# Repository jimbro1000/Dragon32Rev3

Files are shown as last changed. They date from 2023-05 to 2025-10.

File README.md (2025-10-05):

# DRAGON 32 RECREATION Rev 3 #

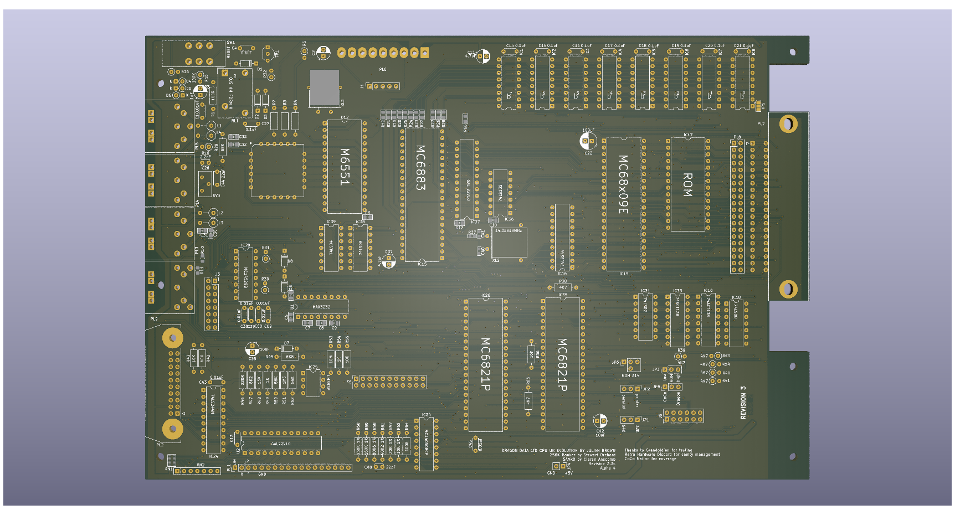
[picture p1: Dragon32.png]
Dragon 32 revision 3 render


This project started as a recreation of the SA2120 CPU Mainboard
for the 1982 Dragon Data **Dragon 32**

Everything (excluding modifications) is taken from the SA2120
schematics. Where this version changes is that the options to
use banks of 16K DRAM is gone, you must use 64K DRAMs, with it
goes all the extra circuitry for configuring the memory for
different types of chip.

The ROM is now a single 27C256 eprom with an option to switch
between two images using JP6 or to allow the rom to be
automatically selected from the PIA.

A second ROM selection jumper is available at JP3 to be used
when a 27C512 is fitted. This swaps the value to A15 between
high and low. When a 27C256 is fitted this must be set low.

Hidden on the back of the board is a solder pad jumper (JP7) that
also needs setting to handle a 27C256 or 27C512. Bridging pad
1 sets pin 22 of the rom to ground, using pad 3 sets the
pin to use the ROM select signal shared with pin 20. When a
27C512 is fitted this must be set to pad 1.

The video circuits have been isolated from the rest of the
board to improve output quality.

A second (internal) cartridge port has been added, by way of
a 2x20 header, along with an additional +5V/Gnd pickup point
for further internal expansion.

An optional 256K banking solution is incorporated using the
design for Stewart Orchard's upgrade board and GAL design.
<https://gitlab.com/sorchard001/dragon-256k-banker-board>

## Progress ##

In the current state (3.3) most of the board is tested except
for the additional audio capabilities, SAMx8 compatibility and
the logic controlled switching of keyboard configuration.

## Modifications ##

### Joysticks ###

The two joystick ports provide a second fire button capability
wired to consecutive keyboard rows, as per the Tandy CoCo.
Unless a two button joystick is used this make no difference to
the operation of the computer. It also requires the use of 6-pin
DIN sockets, these are pin compatible with the 5-pin originals
so a regular single button joystick can still be used.

The two extra buttons can also be disabled by omitting L3 and L4.

### Parallel Port ###

A jumper (JP2) has been introduced to bypass the logic inverter
on the STROBE line. When bypassed the parallel port should
operate as a communication port for DRIVEWIRE.

### Memory Addressing ###

The board is configurable between 32k and 64k ram addressing
using jumper JP1. In most scenarios there is no reason to
disable the 64k option.

The upgrade to 256K needs the 4164s swapping for 41256s. The
pre-bridged jumper at JP5 needs cutting. The SAM also needs 
to be replaced with a 74LS785. The optional components can 
then be fitted and should work without further alteration.

The required JED file for the GAL22V10 that drives the memory
banking is in the CPLD folder of the project.

The 256K upgrade can be replaced with a SAMx8 upgrade board.
This replaces the SAM chip and the tristate buffer that sits
between the RAM and the CPU, and also allows connection to
the second data path that goes to the VDG. With this in place
the DRAM (either 4164 or 41256) is redundant, as is the GAL 
that provides the 256K banker capability.

### Video Port ###

The board includes a third connector for the video mezzanine
card. This exposes the video board to the CPU side of the
data bus along with control signals that would permit 
programming of the video for additional features. With a 
stock 6847 that might be to include a programmable character
"rom" but I'm also working on a synthetic FPGA based replacement
for the 6847 that will allow much bigger changes such as 
swappable/programmable colour palettes.

### Audio ###

The board provides a position to mount a custom implementation
of the AY sound generator. This provides three channels of 
synthesised sound without using the CPU intensive system that
the Dragon comes with by default. The capabilities are the same
as those of the Spectrum 128 models. You can even mix the old
and new methods of sound generation to create more noise!

Theoretically other sound generators could be used but the AY
option provides a cheap, capable mechanism that follows a 
standard familiar to users of other computers from the era.

### Keyboard ###

The board places a GAL chip between the input register of
PIA 1 and the keyboard connector. The GAL could be ommitted
and jumpers used to hardwire the connections to either
Dragon or CoCo compatibility.

With a GAL in place the wiring is controlled by a jumper.

## Substitutions ##

Many of the original components are simply unobtainable or
just very hard (and expensive) to locate. The transistors
will need modern substitutes as the BC141, BC212 and 2N2369
are all obsolete but thankfully these are fairly run-of-the-mill
transistors and shouldn't cause any particular issues.

The CPU and PIAs are all fairly easy to obtain online
and possibly even new (MC6821s are still made and there
are lots of compatible alternatives). A and B rated components
should all be usable but make sure the processor is an "09e".
The Hitachi HD6309 is usable but may cause crashes in some
software due to lazy coding.

Ciaran Anscomb's samX4 can be used to replace the SAM
chip and can be configured to operate as a 74LS783 or a
74LS785 to suit.

### The Future ###

As these parts become harder to find it is inevitable that
replacements and redesigns will be needed. After much hard
work by the Dragon and CoCo community the *only* IC on the
required, that is not still made or in plentiful supply is
the MC6847 VDG (the LM1889 on the PAL board is also in
limited supply but there are ways around the issue).

The Hitachi HD6309 has been in production until recently due
to military supply contracts making it easily accessible and
at reasonable cost. Ultimately this will diminish but with
supplies still high it seems likely to be available for a long
time yet.

The MC6821 is available new but at eye watering prices as
it is only made in small batches. The WD65C21 is a direct
swap and in much higher supply making it generally cheaper
than remaining original NOS parts.

The LS and CD discrete logic chips are all generally easy
to obtain and all have more modern equivalents that can be
swapped in.

Some searching may be needed for the cartridge port connector.
A direct replacement part is listed in the EDAC catalogue but
is only made to demand which requires an order of some 200
units. Lower quality but compatible parts can be found online.

Ultimately all of the parts will become hard to obtain but
for the foreseeable future the board should remain viable.

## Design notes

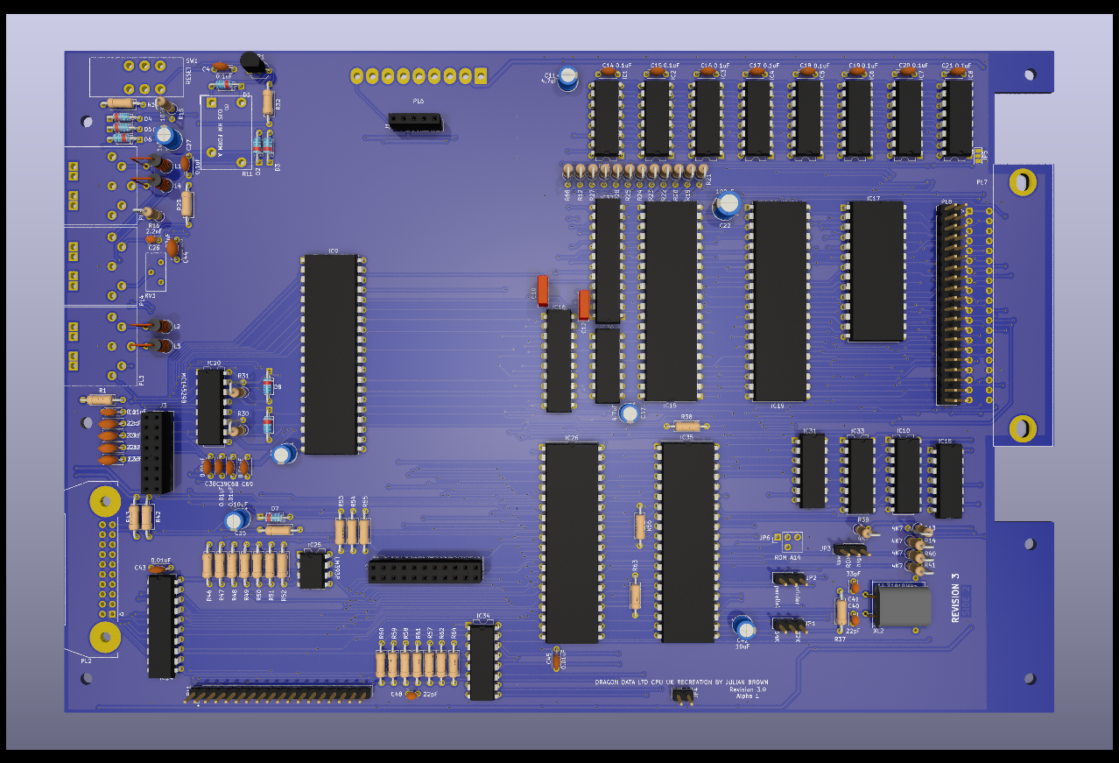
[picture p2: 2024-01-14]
Dragon32plusAlpha1.png

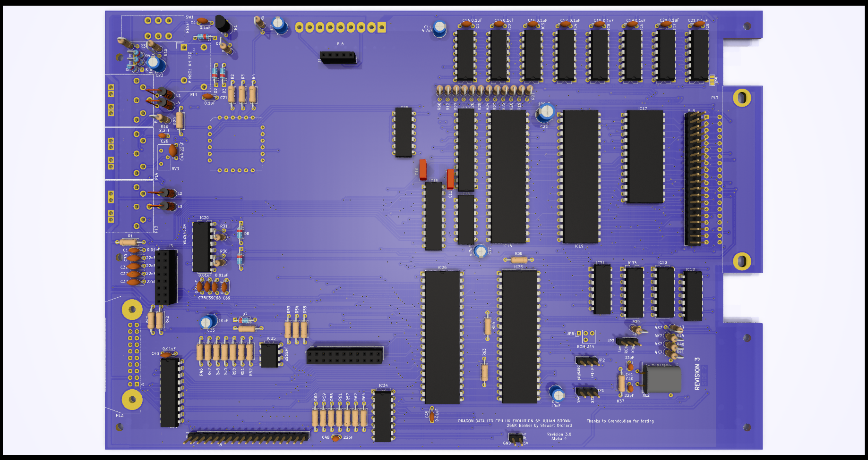
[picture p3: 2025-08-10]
Dragon32plus.png

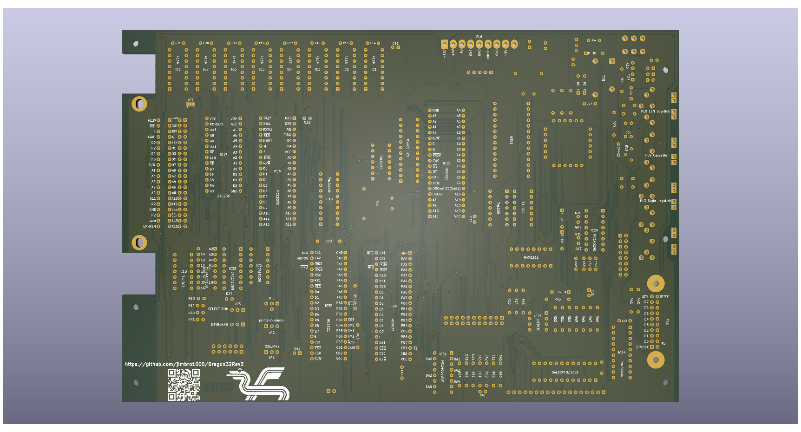
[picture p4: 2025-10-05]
Dragon32reverse.png

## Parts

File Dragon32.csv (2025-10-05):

Reference | Value | Datasheet | Footprint | Qty | DNP | DigiKey | LCSC
C1,C13,C38,C39,C43,C45,C68,C69 | 0.01uF | https://www.vishay.com/docs/45171/kseries.pdf | Capacitor_THT:C_Disc_D4.3mm_W1.9mm_P5.00mm | 8 |  | BC1101CT-ND,BC2662CT-ND
C2,C35,C42 | 10uF | https://www.we-online.com/katalog/datasheet/860010372001.pdf,~ | Capacitor_THT:CP_Radial_D5.0mm_P2.50mm | 3 |  | 732-8593-1-ND
C3,C5,C6,C7,C8,C9,C10,C12 | 100nF | ~ | PCM_Capacitor_SMD_AKL:C_0805_2012Metric_Pad1.18x1.45mm_HandSolder | 8 |  |  | C1711
C4,C14,C15,C16,C17,C18,C19,C20,C21,C27 | 0.1uF | https://www.vishay.com/docs/45171/kseries.pdf | Capacitor_THT:C_Disc_D4.3mm_W1.9mm_P5.00mm | 10 |  | BC1101CT-ND
C11,C37 | 4.7uF | https://datasheets.kyocera-avx.com/tap.pdf | Capacitor_THT:CP_Radial_D5.0mm_P2.50mm | 2 |  | 478-8984-1-ND
C22 | 100uF | https://www.we-online.com/katalog/datasheet/860010372006.pdf | Capacitor_THT:CP_Radial_D6.3mm_P2.50mm | 1 |  | 732-8598-1-ND
C23 | 1uF | https://www.we-online.com/katalog/datasheet/860020772005.pdf | Capacitor_THT:CP_Radial_D5.0mm_P2.50mm | 1 |  | 732-8966-1-ND
C26 | 2.2nF | https://www.vishay.com/docs/45171/kseries.pdf | Capacitor_THT:C_Disc_D3.0mm_W2.0mm_P2.50mm | 1 |  | BC1074CT-ND
C30,C31,C32,C33 | 22nF | https://www.vishay.com/docs/45171/kseries.pdf | PCM_Capacitor_SMD_AKL:C_0805_2012Metric_Pad1.18x1.45mm_HandSolder | 4 |  |  | C1729
C40 | 22pF | https://connect.kemet.com:7667/gateway/IntelliData-ComponentDocumentation/1.0/download/datasheet/C315C220K2G5TA7301 | PCM_Capacitor_SMD_AKL:C_0603_1608Metric_Pad1.08x0.95mm_HandSolder | 1 |  |  | C1653
C41 | 33pF | https://www.vishay.com/docs/45171/kseries.pdf | PCM_Capacitor_SMD_AKL:C_0603_1608Metric_Pad1.08x0.95mm_HandSolder | 1 |  |  | C1663
C44 | 22nF | https://www.vishay.com/docs/45171/kseries.pdf | Capacitor_THT:C_Disc_D5.0mm_W2.5mm_P5.00mm | 1 |  | BC2677CT-ND
C48 | 22pF | https://connect.kemet.com:7667/gateway/IntelliData-ComponentDocumentation/1.0/download/datasheet/C315C220K2G5TA7301 | Capacitor_THT:C_Disc_D3.0mm_W2.0mm_P2.50mm | 1 |  | 399-13930-1-ND
D1,D2,D3,D7,D8,D9 | 1N914 | http://www.vishay.com/docs/85622/1n914.pdf | Diode_THT:D_DO-35_SOD27_P7.62mm_Horizontal | 6 |  | 1N914FS-ND
D4,D5,D6 | 1N914 | http://www.vishay.com/docs/85622/1n914.pdf | Diode_THT:D_DO-35_SOD27_P2.54mm_Vertical_KathodeUp | 3 |  | 1N914FS-ND
IC1,IC2,IC3,IC4,IC5,IC6,IC7,IC8 | 4164 | https://4donline.ihs.com/images/VipMasterIC/IC/INFN/INFNS18263/INFNS18263-1.pdf | Package_DIP:DIP-16_W7.62mm | 8
IC10 | 74ACT138 | http://www.ti.com/lit/gpn/sn74LS138 | Package_DIP:DIP-16_W7.62mm | 1 |  |  | C1547282
IC15 | MC6883 | http://www.colorcomputerarchive.com/coco/Documents/Datasheets/MC6883 Synchronous Address Multiplexer (Motorola).pdf | Package_DIP:DIP-40_W15.24mm | 1
IC16,IC24 | 74LS244N | http://www.ti.com/lit/ds/symlink/sn74ls244.pdf | Package_DIP:DIP-20_W7.62mm | 2 |  | 296-1653-5-ND | C22374098
IC17 | 27C256 | http://ww1.microchip.com/downloads/en/DeviceDoc/doc0014.pdf | Package_DIP:DIP-28_W15.24mm | 1
IC18,IC38 | 74LS08 | http://www.ti.com/lit/gpn/sn74LS08 | Package_DIP:DIP-14_W7.62mm | 2 |  |  | C22394768
IC19 | MC6809E | http://pdf.datasheetcatalog.com/datasheet/motorola/MC68B09S.pdf | Package_DIP:DIP-40_W15.24mm | 1
IC20 | MC14529B |  | Package_DIP:DIP-16_W7.62mm | 1 |  | CD4529BCN-ND
IC25 | LM393P | http://www.ti.com/lit/ds/symlink/lm393.pdf | Package_DIP:DIP-8_W7.62mm | 1 |  | 296-1398-5-ND | C5209
IC26,IC35 | MC6821 |  | Package_DIP:DIP-40_W15.24mm | 2 |  | 2156-MC6821CS-2156-ND
IC31 | 74LS02N | http://www.ti.com/lit/gpn/sn74ls02 | Package_DIP:DIP-14_W7.62mm | 1 |  | 296-1627-5-ND | C22374091
IC33 | 74ACT138N | http://www.ti.com/lit/gpn/sn74LS138 | Package_DIP:DIP-16_W7.62mm | 1 |  | 296-1639-5-ND
IC34 | MC14050BCP | https://media.digikey.com/pdf/Data%20Sheets/ON%20Semiconductor%20PDFs/MC14049B,50B_Rev7.pdf | Package_DIP:DIP-16_W7.62mm | 1 |  | 296-2056-ND
IC36 | 74LS132 | http://www.ti.com/lit/gpn/sn74LS132 | Package_DIP:DIP-14_W7.62mm | 1
IC37 | GAL |  | Package_DIP:DIP-24_W7.62mm | 1
IC39 | 74LS04 | http://www.ti.com/lit/gpn/sn74LS04 | Package_DIP:DIP-14_W7.62mm | 1 |  |  | C22374093
J1 | Video Output Female | ~ | Connector_PinSocket_2.54mm:PinSocket_1x05_P2.54mm_Vertical | 1
J2 | Board Interconnect Female | ~ | Connector_PinSocket_2.54mm:PinSocket_2x11_P2.54mm_Vertical | 1
J3 | Conn_02x08_Odd_Even | ~ | Connector_PinSocket_2.54mm:PinSocket_2x08_P2.54mm_Vertical | 1
J4 | PSG Audio | ~ | Dragon:AY-QTHT | 1
J5 | Config | ~ | Connector_PinHeader_2.54mm:PinHeader_2x06_P2.54mm_Vertical | 1
JP1 | 32k/64k | ~ | Connector_PinHeader_2.54mm:PinHeader_1x03_P2.54mm_Vertical | 1
JP2 | printer/comms | ~ | Connector_PinHeader_2.54mm:PinHeader_1x03_P2.54mm_Vertical | 1
JP3 | SELECT ROM | ~ | Connector_PinHeader_2.54mm:PinHeader_1x03_P2.54mm_Vertical | 1
JP4 | 5vPower | ~ | Connector_PinHeader_2.54mm:PinHeader_1x02_P2.54mm_Vertical | 1
JP5 | Z8hi/low | ~ | Jumper:SolderJumper-3_P1.3mm_Open_Pad1.0x1.5mm | 1
JP6 | ROM A14 |  | Dragon:Jumper_4 | 1
JP7 | 27C512 | ~ | Jumper:SolderJumper-3_P1.3mm_Open_Pad1.0x1.5mm | 1
JP8 | KBD_Config | ~ | Connector_PinHeader_2.54mm:PinHeader_1x03_P2.54mm_Vertical | 1
L1,L2,L3,L4 | 3.3uH | ~ | Inductor_THT:L_Axial_L7.0mm_D3.3mm_P5.08mm_Vertical_Fastron_MICC | 4 |  | 495-5561-1-ND
PL1 | Conn_01x18_Pin | ~ | Connector_PinHeader_2.54mm:PinHeader_1x18_P2.54mm_Vertical | 1
PL2 | Printer | https://media.digikey.com/pdf/Data%20Sheets/CW%20Industries%20PDFs/CWN-300%20Ordering.pdf | Connector_IDC:IDC-Header_2x10-1MP_P2.54mm_Latch_Horizontal | 1 |  | CHR20G-ND
PL3 | DIN-6 J/S R | https://www.dem-uk.com/deltron-components/Data/Product_Downloads/deltron-671-0501-5-way-din-socket-data.pdf | Dragon:DIN-6_DELTRON_671-0601_Horizontal | 1
PL4 | DIN-5 (180) Cassette | https://www.dem-uk.com/deltron-components/Data/Product_Downloads/deltron-671-0501-5-way-din-socket-data.pdf | Dragon:DIN-5_DELTRON_671-0501_45deg_Horizontal | 1
PL5 | DIN-6 J/S L | https://www.dem-uk.com/deltron-components/Data/Product_Downloads/deltron-671-0501-5-way-din-socket-data.pdf | Dragon:DIN-6_DELTRON_671-0601_Horizontal | 1
PL6 | Conn_01x09_Male | https://app.adam-tech.com/products/download/data_sheet/241222/lhd-xx-ts-data-sheet.pdf | Connector_Molex:Molex_KK-396_A-41791-0009_1x09_P3.96mm_Vertical | 1 |  | 2057-LHD-09-TS-ND
PL7 | EDAC 392-040-558-201 | https://files.edac.net/edac/content/342/342-040-558-212%20-%20EDAC%20Card%20Edge%20Connector.PDF | Dragon:Edge_2x20_P2.54mm_OvalMP | 1 |  | 151-395-040-558-201-ND
PL8 | EDAC 392-040-558-201 |  | Connector_PinHeader_2.54mm:PinHeader_2x20_P2.54mm_Vertical | 1 |  | 151-395-040-558-201-ND
PL9 | Serial | http://www.mouser.com/ds/2/18/40_c091_abd_e-75918.pdf | Dragon:DIN-7_DELTRON_671-0701_Horizontal | 1
R1 | 100R | ~ | Resistor_THT:R_Axial_DIN0207_L6.3mm_D2.5mm_P10.16mm_Horizontal | 1 |  | CF14JT100RCT-ND
R2,R3,R4,R49,R54 | 1K | ~ | Resistor_THT:R_Axial_DIN0207_L6.3mm_D2.5mm_P10.16mm_Horizontal | 5 |  | CF14JT1K00CT-ND
R5 | 1K | ~ | Resistor_THT:R_Axial_DIN0207_L6.3mm_D2.5mm_P2.54mm_Vertical | 1
R10,R11 | 4K7 | ~ | Resistor_SMD:R_0805_2012Metric_Pad1.20x1.40mm_HandSolder | 2 |  | CF14JT4K70CT-ND | C17673
R12,R19,R20,R21,R22,R23,R24,R25,R26,R27,R28,R66 | 22R | ~ | PCM_Resistor_SMD_AKL:R_0805_2012Metric_Pad1.20x1.40mm_HandSolder | 12 |  |  | C17561
R13,R14,R30,R31,R32,R39,R40,R41 | 4K7 | ~ | Resistor_THT:R_Axial_DIN0207_L6.3mm_D2.5mm_P2.54mm_Vertical | 8 |  | CF14JT4K70CT-ND
R15,R36 | 100K | ~ | Resistor_THT:R_Axial_DIN0207_L6.3mm_D2.5mm_P2.54mm_Vertical | 2 |  | CF14JT100KCT-ND
R16 | 33K | ~ | Resistor_THT:R_Axial_DIN0207_L6.3mm_D2.5mm_P2.54mm_Vertical | 1 |  | CF14JT33K0CT-ND
R29 | 68K | ~ | Resistor_THT:R_Axial_DIN0207_L6.3mm_D2.5mm_P10.16mm_Horizontal | 1 |  | CF14JT68K0CT-ND
R37 | 1K5 | ~ | PCM_Resistor_SMD_AKL:R_0603_1608Metric_Pad1.05x0.95mm_HandSolder | 1 |  |  | C22843
R38,R63 | 4K7 | ~ | Resistor_THT:R_Axial_DIN0207_L6.3mm_D2.5mm_P10.16mm_Horizontal | 2 |  | CF14JT4K70CT-ND
R42,R43,R55,R56 | 10K | ~ | Resistor_THT:R_Axial_DIN0207_L6.3mm_D2.5mm_P10.16mm_Horizontal | 4 |  | CF14JT10K0CT-ND
R45 | 6K8 | ~ | Resistor_THT:R_Axial_DIN0207_L6.3mm_D2.5mm_P10.16mm_Horizontal | 1 |  | CF14JT6K80CT-ND
R46 | 220R | ~ | Resistor_THT:R_Axial_DIN0207_L6.3mm_D2.5mm_P10.16mm_Horizontal | 1 |  | CF14JT220RCT-ND
R47 | 8K2 | ~ | Resistor_THT:R_Axial_DIN0207_L6.3mm_D2.5mm_P10.16mm_Horizontal | 1 |  | CF14JT8K20CT-ND
R48 | 15K | ~ | Resistor_THT:R_Axial_DIN0207_L6.3mm_D2.5mm_P10.16mm_Horizontal | 1 |  | CF14JT15K0CT-ND
R50,R52 | 56K | ~ | Resistor_THT:R_Axial_DIN0207_L6.3mm_D2.5mm_P10.16mm_Horizontal | 2 |  | CF14JT56K0CT-ND
R51 | 1M5 | ~ | Resistor_THT:R_Axial_DIN0207_L6.3mm_D2.5mm_P10.16mm_Horizontal | 1 |  | CF14JT1M50CT-ND
R53 | 10M | ~ | Resistor_THT:R_Axial_DIN0207_L6.3mm_D2.5mm_P10.16mm_Horizontal | 1 |  | CF14JT10M0CT-ND
R57 | 20K 1% | ~ | Resistor_THT:R_Axial_DIN0207_L6.3mm_D2.5mm_P10.16mm_Horizontal | 1 |  | RNF14FTD20K0CT-ND
R58 | 80K6 1% | ~ | Resistor_THT:R_Axial_DIN0207_L6.3mm_D2.5mm_P10.16mm_Horizontal | 1 |  | RNF14FTD80K6CT-ND
R59 | 160K 1% | ~ | Resistor_THT:R_Axial_DIN0207_L6.3mm_D2.5mm_P10.16mm_Horizontal | 1 |  | S160CACT-ND
R60 | 330K 1% | ~ | Resistor_THT:R_Axial_DIN0207_L6.3mm_D2.5mm_P10.16mm_Horizontal | 1 |  | S330KCACT-ND
R61 | 40K2 1% | ~ | Resistor_THT:R_Axial_DIN0207_L6.3mm_D2.5mm_P10.16mm_Horizontal | 1 |  | RNF14FTD41K2CT-ND
R62 | 10K 1% | ~ | Resistor_THT:R_Axial_DIN0207_L6.3mm_D2.5mm_P10.16mm_Horizontal | 1 |  | RNF14FTD10K0CT-ND
R64 | 100K | ~ | Resistor_THT:R_Axial_DIN0207_L6.3mm_D2.5mm_P10.16mm_Horizontal | 1 |  | CF14JT100KCT-ND
RL1 | OJS HM FORM A | https://www.te.com/commerce/DocumentDelivery/DDEController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 | Dragon:OJS HM 10A Relay | 1 |  | 41-OJS-SH-105HMF,00000-ND
RN1 | 4k7 | ~ | PCM_Resistor_SMD_AKL:R_Array_Convex_8x0602 | 1 | DNP | Y1472CT-ND | C713463
RN2 | 4K7x6 | http://www.vishay.com/docs/31509/csc.pdf | Resistor_THT:R_Array_SIP7 | 1 |  |  | C39096
RV3 | 470R | ~ | Potentiometer_THT:Potentiometer_Bourns_3386X_Horizontal | 1 |  | 3386H-103LF-ND
SW1 | RESET | https://www.ckswitches.com/media/1402/fpush.pdf | Dragon:Button_AlpsAlpine_SPUN190900 | 1 |  | 401-1225-ND
TR1 | PN2222 | http://www.farnell.com/datasheets/296634.pdf | Package_TO_SOT_THT:TO-92_Inline_Wide | 1 |  | KSD1616AYTACT-ND | C896866
U1 | MAX3232 | https://datasheets.maximintegrated.com/en/ds/MAX3222-MAX3241.pdf | Package_DIP:DIP-16_W7.62mm | 1
U2 | GAL22V10 |  | Package_DIP:DIP-24_W7.62mm | 1
U12 | M6551 |  | Package_DIP:DIP-28_W15.24mm | 1
XL2 | 14.31818MHz | https://www.ctscorp.com/wp-content/uploads/MP.pdf | Crystal:Crystal_HC49-U_Horizontal | 1 |  | CTX088-ND
XL3 | 1.8432MHz | ~ | Crystal:Crystal_HC18-U_Horizontal_1EP_style2 | 1

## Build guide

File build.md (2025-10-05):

# Dragon Rev 3 Build Instructions #

## Introduction ##

This is a rough guide on how to assemble the 
Dragon Rev 3 board. It assumes you have 
collected together all the parts you will need 
using the bill of materials in the project 
repository.

## Preparation ##

Any big PCB build requires planning and 
preparation to make things go smoothly. The 
Dragon Rev 3 needs a significant number of 
components, some of them can be hard to obtain.

The choice of video and SAM components make a
substantial difference to how the board is built
and it is worth starting here and working back
from these choices.

Clean the mainboard to remove contaminants, soapy
water first, dry and then a wipe down with 
isopropyl alcohol.

Make sure you have a good supply of solder, a
temperature controlled soldering iron. If you
are using lead based solder set the temperature
to between 320C and 370C - this depends on the 
exact solder composition and the iron being used. 
The board can tolerate higher for lead-free solder.

A ready supply of solder flux can be really
helpful if you find yourself having to remove a
component from the board.

You will need short tipped, angled wire cutters
for trimming the component leads after soldering.
Don't cut the leads right down to the board or deep
into the solder.

It is also a good idea to have a multimeter on hand
to check component values and test for any shorts
after soldering.

The project repository on GitHub includes an
interactive Bill Of Materials that allows you to
cross-reference components against position on
the board (and mark off all the parts that you've
fitted). To use this download the ibom.html file
to your computer and open it from the local file
system (this should open up a web browser).

If you can't or don't want to use the iBOM it is
a good idea to print off the Dragon Assembly 
PDF on to large form paper and mark the positions 
off from there as they are fitted to help avoid
getting lost.

## Build Order ##

It is advised to work with the lowest profile
components first - resistors, then diodes, then 
capacitors, transistors, etc.

Leaving the chip sockets until last helps as they 
tend to get in the way when fitting other items.

### Build Options ###

The board can be built to three different 
configurations:

    1. 64K with standard SAM
    2. 256K with updated 74LS785 SAM
    3. 512K with SAMx8

### SMD Parts ###

Build option 1 and 2 require that the surface
mount resistors North of the SAM position must
be fitted.

For option 2 the capacitors at C12 and C10 are
required.

RN1 is not required if RN2 is fitted (and
vice-versa).

The remaining SMD parts are required for all
three build options.

### Through Hole Resistors ###

Fit resistors first making sure the solder is
forming on both sides of the board, not just
the bottom.

Regardless of board configuration all of the
resistors should be fitted.

Save the two potentiometer resistors RV1 and RV2
for later.

### Diodes ###

Fit all 9 diodes in much the same way as the
resistors but making sure the polarity marking
matches the board. D4, D5 and D6 all require
the cathode to face up. The cathode should be
connected to the pad labelled K

### Inductors ###

If you want to have the option of two button
joysticks (non-standard but used in some
CoCo games) then you'll need to fit all 4
inductors (L1-L4).

If you only want single button joysticks you
only need to fit L1 and L2.

Soldering is the same as for resistors.

### Through Hole Capacitors ###

If you are building option 1 or 2, C14
to C21 must be fitted.

Other than this fit all capacitors making 
sure that the tantalum and electrolytic
capacitors are fitted the right way around.

Tantalum capacitors have a + symbol next to
the positive side. Electrolytic capacitors
have an arrow pointing to the negative side.

The board is marked to show a + next to the
positive side and a filled semicircle on the
negative side.

It is worth saving two of the long legs
after trimming the legs back. You can use
these for securing the crystals.

Save the trim pot capacitor C7 for later.

### Transistors ###

TR1 is an NPN transistor driving the coil of
the cassette remote relay. It uses a wide
TO-92 footprint.

Make sure the transistor is fitted the
right way around according to the outline
printed on the board.

### Jumper Posts ###

The board has 5 sets of jumpers that
need to be fitted with clips.

JP1 sets the RAM size if the board is
to be used as a Dragon 32.

JP2 controls whether the printer strobe
signal is inverted or not. For regular
printer use the "printer" option must
be used. If the strobe is to be used as
a bit-bang serial port (for drivewire
or CoCo compatibility), the "parallel"
option must be used.

JP3 allows you to control pin A15 of the
ROM. This is only relevant if the ROM
is a 27C512.

JP6 controls pin A14 of the ROM. There are
3 options, high, low or PIA controlled.
The PIA controlled setting is used by the
Dragon 64. This is only of use for a
27C256 or 27C512 rom.

JP8 configures the keyboard matrix
connections to switch between Dragon
and CoCo standards (using a Dragon
keyboard).

### Solder Jumpers ###

JP5 is used to fix the signal to Z8.
This is useful if 64k chips are used or
256k chips need to be used without a
74LS785 SAM.

### Connectors ###

The keyboard connector can be vertical or
a horizontal as desired. Original boards
used a vertical orientation but later boards
and the D64 moved to horizontal to avoid 
clashing with the keyboard itself. I
recommend using the horizontal option as
it leaves more space for connectors.

The joystick, serial and cassette port 
connectors have an overlapping design, if 
you want to get them nicely lined up start 
with the 5-pin cassette socket and tack it 
in place on a single pin.

You can then do the same with the two
joystick ports (6-pin or 270deg 5-pin)
and align them to the edge of the board.
This can be a tricky task so don't rush
it.

The power board connector needs to be 
fitted with the vertical guide towards
the bottom of the board (assuming you
don't have a plain pin header).

The cartridge port connector can be very
entertaining to fit. The pins like to
bend in transit so you'll likely find
yours do not line up on the first attempt.
It is very easy to bend the pins on the
cheaper connectors resulting in the pin
not fitting properly. Double check that
all pins have fitted through the mounting
holes on the board before soldering.

### Variable Components ###

RV3 needs to be fitted at an angle if
it is adjusted from the side.

### Crystals ###

Assuming you have the larger housed
crystals you will need to bend the legs
so the crystal lies flush with the board.
This is not essential but it is 
recommended. Two additional solder points
are provided for each crystal to allow a
wire to be formed over the body and 
prevent the crystal being moved. A
convenient source for the wire to do this
is the long legged capacitors you 
hopefully saved earlier.

### Sockets ###

When fitting the sockets make sure the
orientation is correct and the notch of
the socket matches the outline on the
board.

Most of the chips are aligned with the 
notch to the top of the board but RAM, ROM
and SAM chips have the notch towards
the bottom of the board.

As with the header pins it can be a 
little tricky to get the sockets to fit
flush and aligned. Tacking one pin at 
each end of the socket to hold it in
place and then heating one pin while
adjusting the position gives a good
result.

Be very careful to avoid bridging the
pins on the socket while soldering.
It is worth checking with a multimeter
to double check as the pins can 
bridge on the top of the board, hidden
underneath the socket.

### Before Fitting Chips ###

As a precaution, before fitting the
chips to the board it is worth making
sure none of the voltage pins of the
power board connector are shorted to
ground (that would be bad).

### Fitting Chips ###

Make sure you have a grounding strap on your
wrist (or ankle) and it is actually connected
to a proven ground point (radiators are a 
good source). The LM1889 and DRAM chips are
very susceptible to static discharge! Leave
these until last.

Fit all your chips paying very careful attention
to orientation, notches must match with the
board. Fitting chips the wrong way round will 
likely destroy them when the power is switched
on.

### Keyboard Connection ###

The keyboard must be fitted to the right of
the arrow on PL1. The two pins to the left
are used for providing power to the keyboard.

### First Power Up ###

When powering on for the first time always be
prepared to turn the power off in a hurry. 

If anything smokes or looks to be getting hot, turn
the power off immediately. You most likely have a 
short (you did check for shorts?) or a polarised
capacitor in backwards.

### Troubleshooting ###

If the relay doesn't click on powering up (assuming
you fitted one) and there is no picture at all, the
chances are the CPU is not cycling. Either it hasn't
come out of reset or is being locked up by another
line.

A bad PIA can cause the CPU to run very, very slowly
by generating interrupt requests at high frequency.
Try removing the PIAs and try running without them.

Check the reset line is going high (about 5V) and the
same again for halt, mrdy, extal, xtal, bs and ba pins.
If any of these are low it can stop the CPU operating.

Check the Q and E pins are oscillating at (about) 
0.9MHz, no clock means no CPU. You can also check
the SAM is receiving the full 14MHz clock from the
crystal.

If all is well with those pins, test the address and
data lines with an oscilloscope or logic probe. You
should see activity with the lines moving from high
to low.

If the CPU is doing nothing it may be faulty, either
test the CPU in a known good machine or try a different
CPU.

If the CPU is proven good you can turn your attention
to the SAM, this governs the CPU activity and memory
addressing. I've yet to see one fail but if it does
you have no hope of getting the computer to work until
it is replaced. More likely the SAM is not getting 
the input signals it needs to operate.

Check the clock input and the Q/E output of the SAM.
If the clock is present and correct, check the SAM 
is generating RAM addressing signals on the Z lines 
and RAS/CAS lines.

The SAM also decides what device is being addressed
it does this though a multiplexer at IC33. Check the
operation of this chip carefully. 

## Options ##

### Keyboard ###

If there is no need to support a CoCo keyboard setup
the GAL at U2 can be omitted. Instead just connect
the pins across the chip. Don't connect the top pair
as these are power and ground. RN1/2 can also be
omitted.

If it is required the GAL can be a 16V8 or 22V10, in
both cases the chip must be fitted to the left end
of the socket. RN1 or RN2 must be fitted if a GAL is
used.

### Serial Port ###

The RS232 setup can be omitted if the board is to
be used as a Dragon 32 or CoCo. In this scenario
U1, U12, IC38, IC39, XL3 and PL9 can all be omitted from
the build.

### Video ###

The board is designed to work with separate plug-in
video boards. At the simplest end these are either
NTSC or PAL composite output. More complex solutions
can be switched between formats, include the lower-case
extension or extended video options.

The video board is *not* part of this design and needs
to be obtained separately.

### SAM ###

The original SN74LS783 / MC6883 SAM chip limits the 
board to using 4164 64kb x 1 DRAM chips with 128 
row refresh (256 row refresh will not work).

A later, optional, version of the SAM chip is
available. Still with the Motorola MC6883 code but
with the logic identifier SN74LS785. These extend
the compatibility options to use 256 row refresh
DRAM chips. This version of the SAM chip is needed
for the 256kb x 1 DRAM chips. Obtaining this version
of the SAM can be tricky, if you plan to build the
256k version of the board please make sure you have
the chip first to avoid disappointment.

It is possible to use a modern replacement for the
SAM courtesy of Ciaran Anscomb. The preferred 
option is the SAMx8 plugin board that replaces the
SAM chip completely (and RAM).

See https://www.6809.org.uk/dragon/samx8/ for more
details.

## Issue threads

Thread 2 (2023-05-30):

DSD signal is not wired on phase 2

jimbro1000, 2023-05-30:
The DSD safety feature is missing in the phase 2 design and needs adding in

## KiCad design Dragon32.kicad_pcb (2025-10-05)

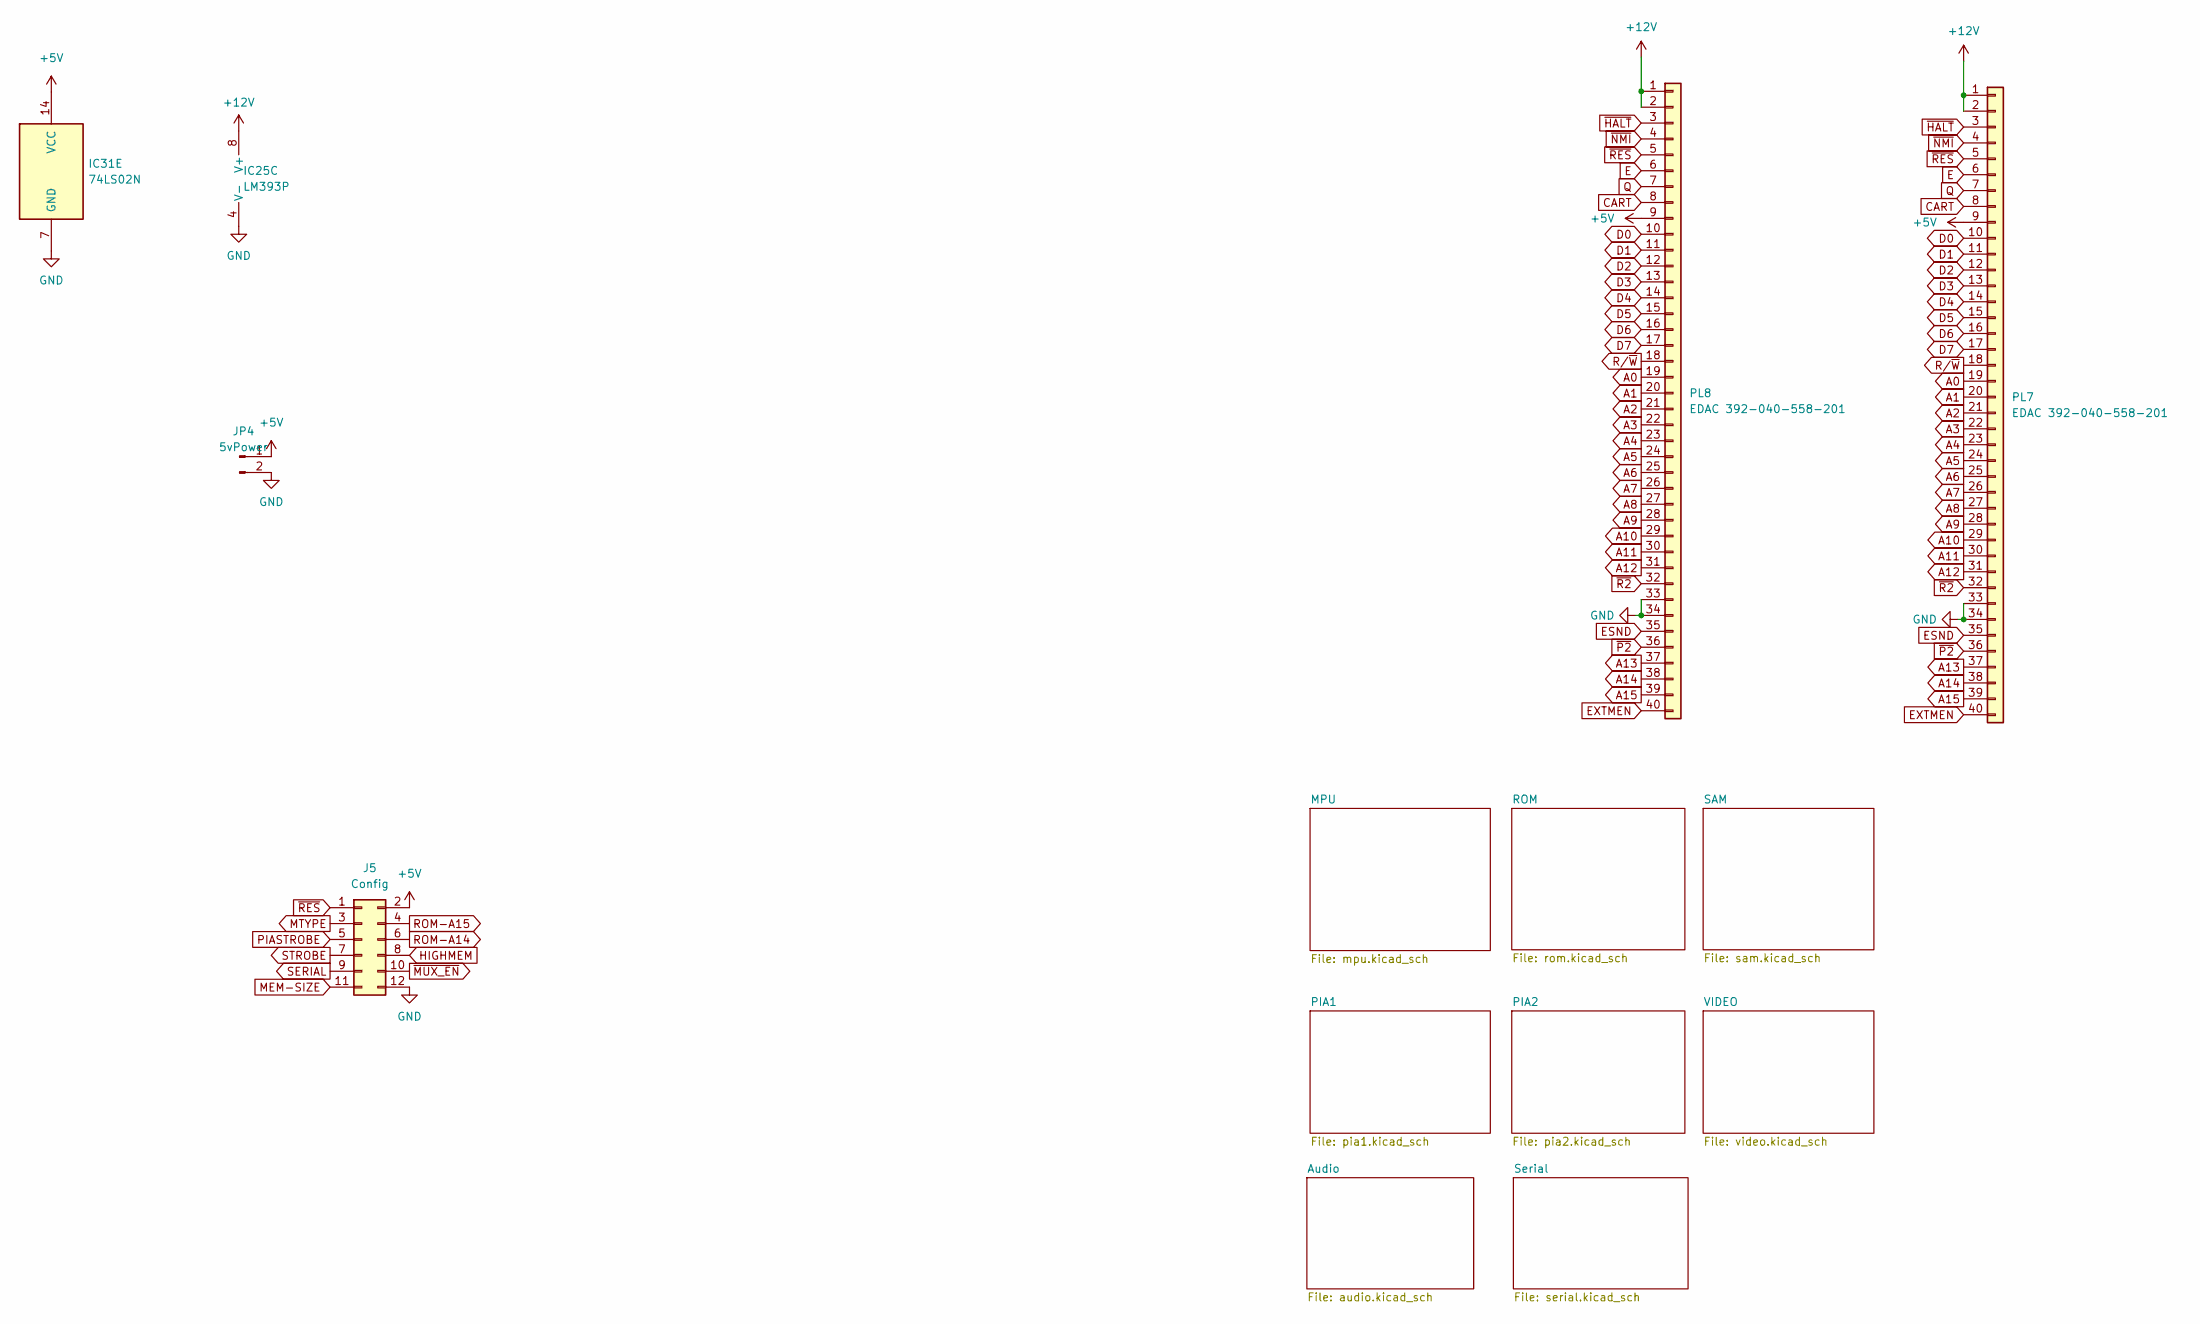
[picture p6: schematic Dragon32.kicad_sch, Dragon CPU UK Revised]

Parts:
IC25: LM393P; DIP-8_W7.62mm; DigiKey 296-1398-5-ND
IC31: 74LS02N; DIP-14_W7.62mm; DigiKey 296-1627-5-ND
J5: Config; PinHeader_2x06_P2.54mm_Vertical
JP4: 5vPower; PinHeader_1x02_P2.54mm_Vertical
PL7: EDAC 392-040-558-201; Edge_2x20_P2.54mm_OvalMP; DigiKey 151-395-040-558-201-ND
PL8: EDAC 392-040-558-201; PinHeader_2x20_P2.54mm_Vertical; DigiKey 151-395-040-558-201-ND

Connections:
+5V: IC31.14 (VCC), J5.2, JP4.1, PL7.9, PL8.9; also elsewhere on the board
+12V: IC25.8 (V+), PL7.1, PL7.2, PL8.1, PL8.2; also elsewhere on the board
A0: PL7.19, PL8.19; also elsewhere on the board
A1: PL7.20, PL8.20; also elsewhere on the board
A2: PL7.21, PL8.21; also elsewhere on the board
A3: PL7.22, PL8.22; also elsewhere on the board
A4: PL7.23, PL8.23; also elsewhere on the board
A5: PL7.24, PL8.24; also elsewhere on the board
A6: PL7.25, PL8.25; also elsewhere on the board
A7: PL7.26, PL8.26; also elsewhere on the board
A8: PL7.27, PL8.27; also elsewhere on the board
A9: PL7.28, PL8.28; also elsewhere on the board
A10: PL7.29, PL8.29; also elsewhere on the board
A11: PL7.30, PL8.30; also elsewhere on the board
A12: PL7.31, PL8.31; also elsewhere on the board
A13: PL7.37, PL8.37; also elsewhere on the board
A14: PL7.38, PL8.38; also elsewhere on the board
A15: PL7.39, PL8.39; also elsewhere on the board
CART: PL7.8, PL8.8; also elsewhere on the board
D0: PL7.10, PL8.10; also elsewhere on the board
D1: PL7.11, PL8.11; also elsewhere on the board
D2: PL7.12, PL8.12; also elsewhere on the board
D3: PL7.13, PL8.13; also elsewhere on the board
D4: PL7.14, PL8.14; also elsewhere on the board
D5: PL7.15, PL8.15; also elsewhere on the board
D6: PL7.16, PL8.16; also elsewhere on the board
D7: PL7.17, PL8.17; also elsewhere on the board
E: PL7.6, PL8.6; also elsewhere on the board
ESND: PL7.35, PL8.35; also elsewhere on the board
EXTMEN: PL7.40, PL8.40; also elsewhere on the board
HIGHMEM: J5.8; also elsewhere on the board
MEM-SIZE: J5.11; also elsewhere on the board
MTYPE: J5.3; also elsewhere on the board
PIASTROBE: J5.5; also elsewhere on the board
Q: PL7.7, PL8.7; also elsewhere on the board
ROM-A14: J5.6; also elsewhere on the board
ROM-A15: J5.4; also elsewhere on the board
R/~W: PL7.18, PL8.18; also elsewhere on the board
SERIAL: J5.9; also elsewhere on the board
STROBE: J5.7; also elsewhere on the board
~HALT: PL7.3, PL8.3; also elsewhere on the board
~MUX_EN: J5.10; also elsewhere on the board
~NMI: PL7.4, PL8.4; also elsewhere on the board
~P2: PL7.36, PL8.36; also elsewhere on the board
~R2: PL7.32, PL8.32; also elsewhere on the board
~RES: J5.1, PL7.5, PL8.5; also elsewhere on the board

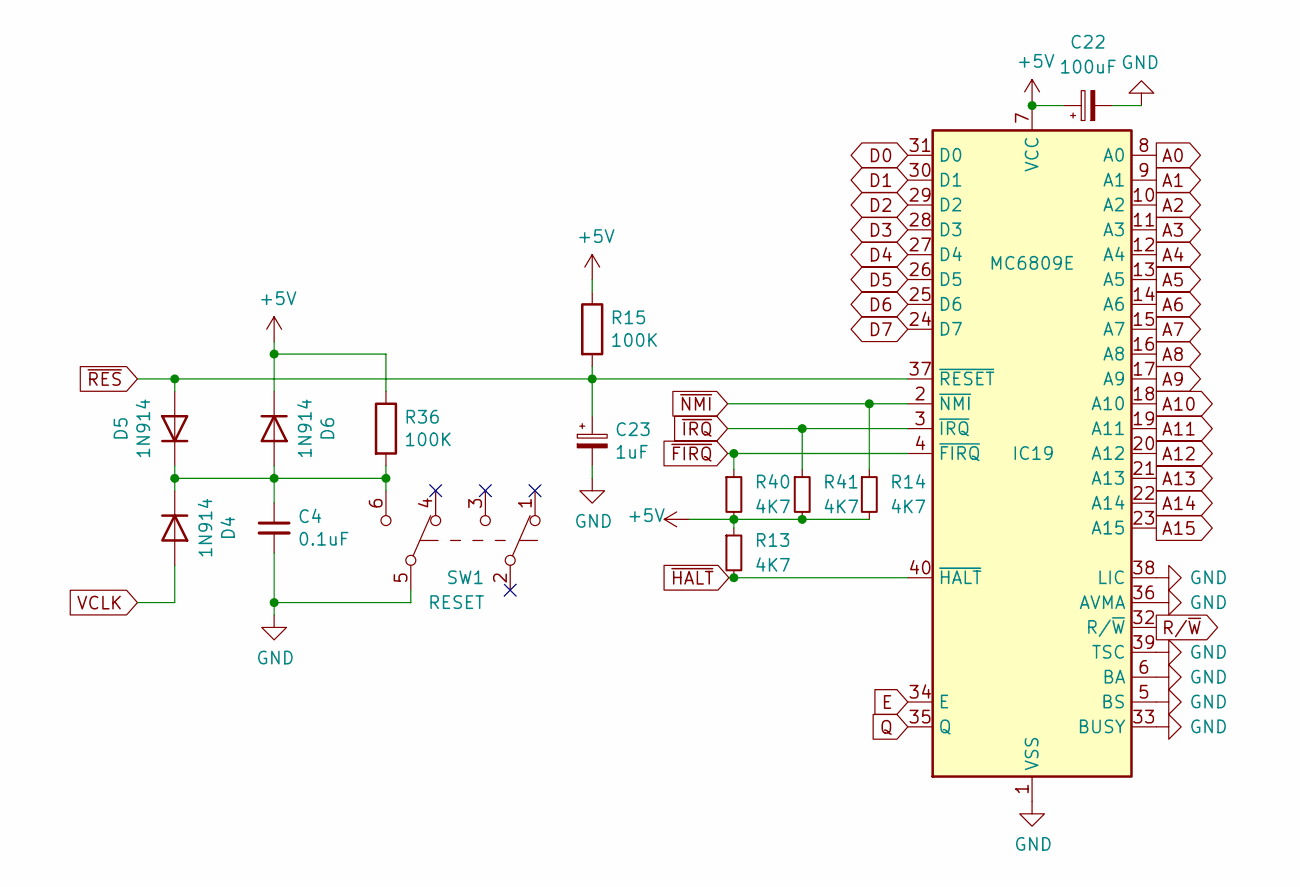
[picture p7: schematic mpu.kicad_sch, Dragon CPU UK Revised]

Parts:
C4: 0.1uF; C_Disc_D4.3mm_W1.9mm_P5.00mm; DigiKey BC1101CT-ND
C22: 100uF; CP_Radial_D6.3mm_P2.50mm; DigiKey 732-8598-1-ND
C23: 1uF; CP_Radial_D5.0mm_P2.50mm; DigiKey 732-8966-1-ND
D4, D5, D6: 1N914; D_DO-35_SOD27_P2.54mm_Vertical_KathodeUp; DigiKey 1N914FS-ND
IC19: MC6809E; DIP-40_W15.24mm
R13, R14, R40, R41: 4K7; R_Axial_DIN0207_L6.3mm_D2.5mm_P2.54mm_Vertical; DigiKey CF14JT4K70CT-ND
R15, R36: 100K; R_Axial_DIN0207_L6.3mm_D2.5mm_P2.54mm_Vertical; DigiKey CF14JT100KCT-ND
SW1: RESET; Button_AlpsAlpine_SPUN190900; DigiKey 401-1225-ND

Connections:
+5V: C22.1, D6.1 (K), IC19.7 (VCC), R13.1, R14.2, R15.1, R36.1, R40.2, R41.2; also elsewhere on the board
A0: IC19.8 (A0); also elsewhere on the board
A1: IC19.9 (A1); also elsewhere on the board
A2: IC19.10 (A2); also elsewhere on the board
A3: IC19.11 (A3); also elsewhere on the board
A4: IC19.12 (A4); also elsewhere on the board
A5: IC19.13 (A5); also elsewhere on the board
A6: IC19.14 (A6); also elsewhere on the board
A7: IC19.15 (A7); also elsewhere on the board
A8: IC19.16 (A8); also elsewhere on the board
A9: IC19.17 (A9); also elsewhere on the board
A10: IC19.18 (A10); also elsewhere on the board
A11: IC19.19 (A11); also elsewhere on the board
A12: IC19.20 (A12); also elsewhere on the board
A13: IC19.21 (A13); also elsewhere on the board
A14: IC19.22 (A14); also elsewhere on the board
A15: IC19.23 (A15); also elsewhere on the board
D0: IC19.31 (D0); also elsewhere on the board
D1: IC19.30 (D1); also elsewhere on the board
D2: IC19.29 (D2); also elsewhere on the board
D3: IC19.28 (D3); also elsewhere on the board
D4: IC19.27 (D4); also elsewhere on the board
D5: IC19.26 (D5); also elsewhere on the board
D6: IC19.25 (D6); also elsewhere on the board
D7: IC19.24 (D7); also elsewhere on the board
E: IC19.34 (E); also elsewhere on the board
unnamed: C4.1, D4.1 (K), D5.1 (K), D6.2 (A), R36.2, SW1.6 (C)
Q: IC19.35 (Q); also elsewhere on the board
R/~W: IC19.32 (R/~W); also elsewhere on the board
VCLK: D4.2 (A); also elsewhere on the board
~FIRQ: IC19.4 (~FIRQ), R40.1; also elsewhere on the board
~HALT: IC19.40 (~HALT), R13.2; also elsewhere on the board
~IRQ: IC19.3 (~IRQ), R41.1; also elsewhere on the board
~NMI: IC19.2 (~NMI), R14.1; also elsewhere on the board
~RES: C23.1, D5.2 (A), IC19.37 (~RESET), R15.2; also elsewhere on the board

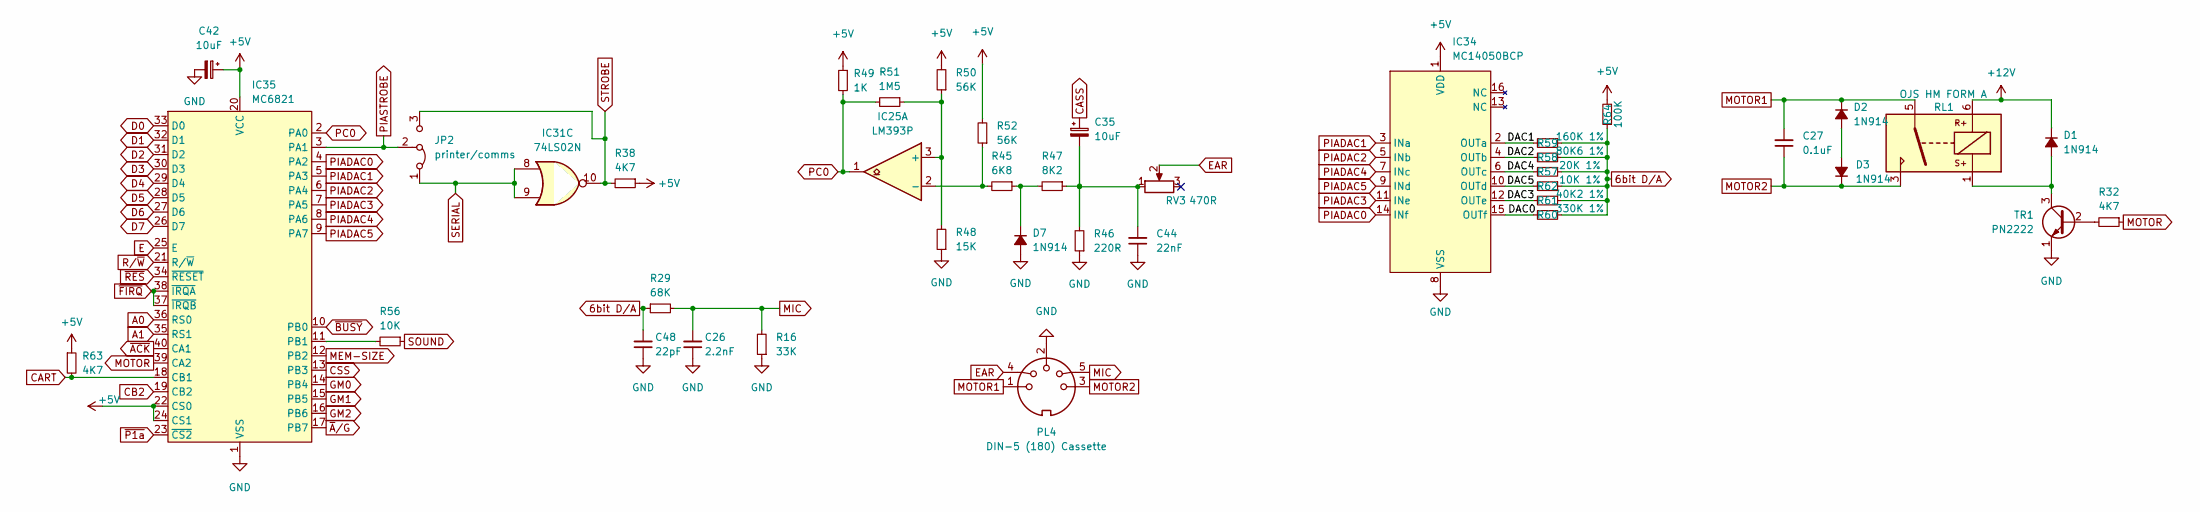
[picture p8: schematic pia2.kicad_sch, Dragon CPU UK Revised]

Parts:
C26: 2.2nF; C_Disc_D3.0mm_W2.0mm_P2.50mm; DigiKey BC1074CT-ND
C27: 0.1uF; C_Disc_D4.3mm_W1.9mm_P5.00mm; DigiKey BC1101CT-ND
C35, C42: 10uF; CP_Radial_D5.0mm_P2.50mm; DigiKey 732-8593-1-ND
C44: 22nF; C_Disc_D5.0mm_W2.5mm_P5.00mm; DigiKey BC2677CT-ND
C48: 22pF; C_Disc_D3.0mm_W2.0mm_P2.50mm; DigiKey 399-13930-1-ND
D1, D2, D3, D7: 1N914; D_DO-35_SOD27_P7.62mm_Horizontal; DigiKey 1N914FS-ND
IC25: LM393P; DIP-8_W7.62mm; DigiKey 296-1398-5-ND
IC31: 74LS02N; DIP-14_W7.62mm; DigiKey 296-1627-5-ND
IC34: MC14050BCP; DIP-16_W7.62mm; DigiKey 296-2056-ND
IC35: MC6821; DIP-40_W15.24mm; DigiKey 2156-MC6821CS-2156-ND
JP2: printer/comms; PinHeader_1x03_P2.54mm_Vertical
PL4: DIN-5 (180) Cassette; DIN-5_DELTRON_671-0501_45deg_Horizontal
R16: 33K; R_Axial_DIN0207_L6.3mm_D2.5mm_P2.54mm_Vertical; DigiKey CF14JT33K0CT-ND
R29: 68K; R_Axial_DIN0207_L6.3mm_D2.5mm_P10.16mm_Horizontal; DigiKey CF14JT68K0CT-ND
R32: 4K7; R_Axial_DIN0207_L6.3mm_D2.5mm_P2.54mm_Vertical; DigiKey CF14JT4K70CT-ND
R38, R63: 4K7; R_Axial_DIN0207_L6.3mm_D2.5mm_P10.16mm_Horizontal; DigiKey CF14JT4K70CT-ND
R45: 6K8; R_Axial_DIN0207_L6.3mm_D2.5mm_P10.16mm_Horizontal; DigiKey CF14JT6K80CT-ND
R46: 220R; R_Axial_DIN0207_L6.3mm_D2.5mm_P10.16mm_Horizontal; DigiKey CF14JT220RCT-ND
R47: 8K2; R_Axial_DIN0207_L6.3mm_D2.5mm_P10.16mm_Horizontal; DigiKey CF14JT8K20CT-ND
R48: 15K; R_Axial_DIN0207_L6.3mm_D2.5mm_P10.16mm_Horizontal; DigiKey CF14JT15K0CT-ND
R49: 1K; R_Axial_DIN0207_L6.3mm_D2.5mm_P10.16mm_Horizontal; DigiKey CF14JT1K00CT-ND
R50, R52: 56K; R_Axial_DIN0207_L6.3mm_D2.5mm_P10.16mm_Horizontal; DigiKey CF14JT56K0CT-ND
R51: 1M5; R_Axial_DIN0207_L6.3mm_D2.5mm_P10.16mm_Horizontal; DigiKey CF14JT1M50CT-ND
R56: 10K; R_Axial_DIN0207_L6.3mm_D2.5mm_P10.16mm_Horizontal; DigiKey CF14JT10K0CT-ND
R57: 20K 1%; R_Axial_DIN0207_L6.3mm_D2.5mm_P10.16mm_Horizontal; DigiKey RNF14FTD20K0CT-ND
R58: 80K6 1%; R_Axial_DIN0207_L6.3mm_D2.5mm_P10.16mm_Horizontal; DigiKey RNF14FTD80K6CT-ND
R59: 160K 1%; R_Axial_DIN0207_L6.3mm_D2.5mm_P10.16mm_Horizontal; DigiKey S160CACT-ND
R60: 330K 1%; R_Axial_DIN0207_L6.3mm_D2.5mm_P10.16mm_Horizontal; DigiKey S330KCACT-ND
R61: 40K2 1%; R_Axial_DIN0207_L6.3mm_D2.5mm_P10.16mm_Horizontal; DigiKey RNF14FTD41K2CT-ND
R62: 10K 1%; R_Axial_DIN0207_L6.3mm_D2.5mm_P10.16mm_Horizontal; DigiKey RNF14FTD10K0CT-ND
R64: 100K; R_Axial_DIN0207_L6.3mm_D2.5mm_P10.16mm_Horizontal; DigiKey CF14JT100KCT-ND
RL1: OJS HM FORM A; OJS HM 10A Relay; DigiKey 41-OJS-SH-105HMF,00000-ND
RV3: 470R; Potentiometer_Bourns_3386X_Horizontal; DigiKey 3386H-103LF-ND
TR1: PN2222; TO-92_Inline_Wide; DigiKey KSD1616AYTACT-ND

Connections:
6bit D/A: C48.2, R29.1, R57.1, R58.1, R59.1, R60.1, R61.1, R62.1, R64.1; also elsewhere on the board
+5V: C42.1, IC34.1 (VDD), IC35.20 (VCC), IC35.22 (CS0), IC35.24 (CS1), R38.1, R49.1, R50.2, R52.2, R63.1, R64.2; also elsewhere on the board
+12V: D1.1 (K), RL1.6; also elsewhere on the board
/PIA2/DAC0: IC34.15 (OUTf), R60.2
/PIA2/DAC1: IC34.2 (OUTa), R59.2
/PIA2/DAC2: IC34.4 (OUTb), R58.2
/PIA2/DAC3: IC34.12 (OUTe), R61.2
/PIA2/DAC4: IC34.6 (OUTc), R57.2
/PIA2/DAC5: IC34.10 (OUTd), R62.2
A0: IC35.36 (RS0); also elsewhere on the board
A1: IC35.35 (RS1); also elsewhere on the board
CART: IC35.18 (CB1), R63.2; also elsewhere on the board
CASS: C35.1; also elsewhere on the board
CB2: IC35.19 (CB2); also elsewhere on the board
CSS: IC35.13 (PB3); also elsewhere on the board
D0: IC35.33 (D0); also elsewhere on the board
D1: IC35.32 (D1); also elsewhere on the board
D2: IC35.31 (D2); also elsewhere on the board
D3: IC35.30 (D3); also elsewhere on the board
D4: IC35.29 (D4); also elsewhere on the board
D5: IC35.28 (D5); also elsewhere on the board
D6: IC35.27 (D6); also elsewhere on the board
D7: IC35.26 (D7); also elsewhere on the board
E: IC35.25 (E); also elsewhere on the board
EAR: PL4.4, RV3.2
GM0: IC35.14 (PB4); also elsewhere on the board
GM1: IC35.15 (PB5); also elsewhere on the board
GM2: IC35.16 (PB6); also elsewhere on the board
MEM-SIZE: IC35.12 (PB2); also elsewhere on the board
MIC: C26.2, PL4.5, R16.2, R29.2
MOTOR: IC35.39 (CA2), R32.1
MOTOR1: C27.2, D2.1 (K), PL4.1, RL1.5
MOTOR2: C27.1, D3.1 (K), PL4.3, RL1.3
unnamed: C35.2, C44.2, R46.2, R47.1, RV3.1
unnamed: D1.2 (A), RL1.1, TR1.3 (C)
unnamed: D2.2 (A), D3.2 (A)
unnamed: D7.1 (K), R45.1, R47.2
unnamed: IC25.3 (+), R48.2, R50.1, R51.1
unnamed: IC25.2 (-), R45.2, R52.1
unnamed: IC35.11 (PB1), R56.2
unnamed: R32.2, TR1.2 (B)
PC0: IC25.1, IC35.2 (PA0), R49.2, R51.2
PIADAC0: IC34.14 (INf), IC35.4 (PA2)
PIADAC1: IC34.3 (INa), IC35.5 (PA3)
PIADAC2: IC34.5 (INb), IC35.6 (PA4)
PIADAC3: IC34.11 (INe), IC35.7 (PA5)
PIADAC4: IC34.7 (INc), IC35.8 (PA6)
PIADAC5: IC34.9 (INd), IC35.9 (PA7)
PIASTROBE: IC35.3 (PA1), JP2.2 (C); also elsewhere on the board
R/~W: IC35.21 (R/~W); also elsewhere on the board
SERIAL: IC31.8, IC31.9, JP2.1 (A); also elsewhere on the board
SOUND: R56.1; also elsewhere on the board
STROBE: IC31.10, JP2.3 (B), R38.2; also elsewhere on the board
~ACK: IC35.40 (CA1); also elsewhere on the board
~A/G: IC35.17 (PB7); also elsewhere on the board
~BUSY: IC35.10 (PB0); also elsewhere on the board
~FIRQ: IC35.37 (~IRQB), IC35.38 (~IRQA); also elsewhere on the board
~P1a: IC35.23 (~CS2); also elsewhere on the board
~RES: IC35.34 (~RESET); also elsewhere on the board

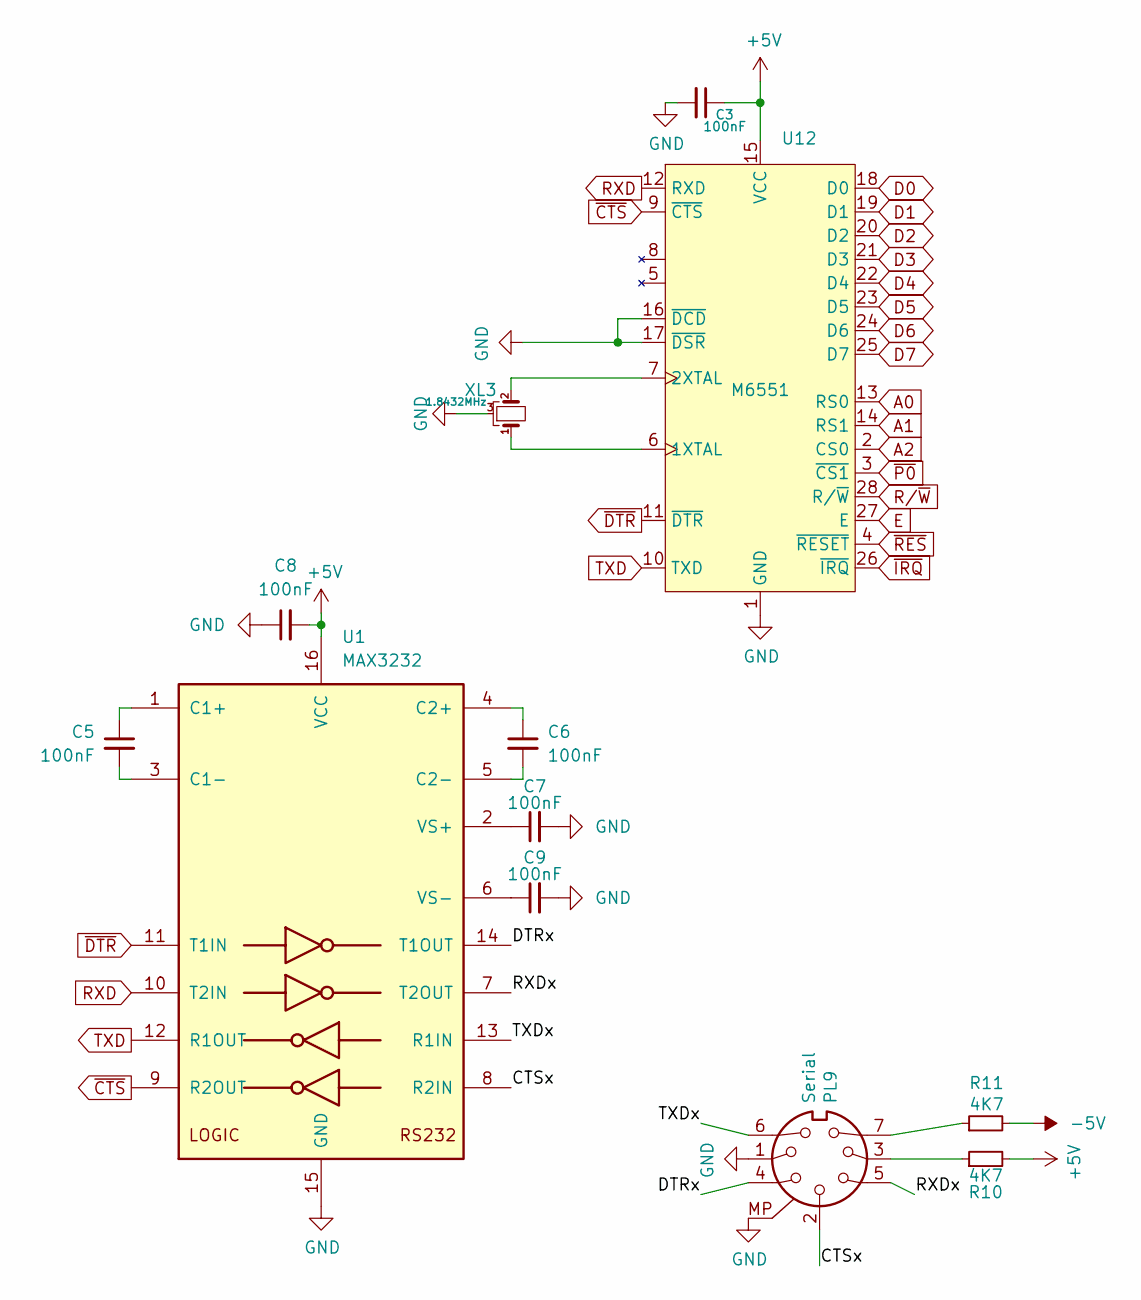
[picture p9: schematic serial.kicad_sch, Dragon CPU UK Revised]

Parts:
C3, C5, C6, C7, C8, C9: 100nF; C_0805_2012Metric_Pad1.18x1.45mm_HandSolder; LCSC C1711
PL9: Serial; DIN-7_DELTRON_671-0701_Horizontal
R10, R11: 4K7; R_0805_2012Metric_Pad1.20x1.40mm_HandSolder; DigiKey CF14JT4K70CT-ND
U1: MAX3232; DIP-16_W7.62mm
U12: M6551; DIP-28_W15.24mm
XL3: 1.8432MHz; Crystal_HC18-U_Horizontal_1EP_style2

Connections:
+5V: C3.1, C8.2, R10.2, U1.16 (VCC), U12.15 (VCC); also elsewhere on the board
-5V: R11.2; also elsewhere on the board
/Serial/CTSx: PL9.2, U1.8 (R2IN)
/Serial/DTRx: PL9.4, U1.14 (T1OUT)
/Serial/RXDx: PL9.5, U1.7 (T2OUT)
/Serial/TXDx: PL9.6, U1.13 (R1IN)
A0: U12.13 (RS0); also elsewhere on the board
A1: U12.14 (RS1); also elsewhere on the board
A2: U12.2 (CS0); also elsewhere on the board
D0: U12.18 (D0); also elsewhere on the board
D1: U12.19 (D1); also elsewhere on the board
D2: U12.20 (D2); also elsewhere on the board
D3: U12.21 (D3); also elsewhere on the board
D4: U12.22 (D4); also elsewhere on the board
D5: U12.23 (D5); also elsewhere on the board
D6: U12.24 (D6); also elsewhere on the board
D7: U12.25 (D7); also elsewhere on the board
E: U12.27 (E); also elsewhere on the board
unnamed: PL9.3, R10.1
unnamed: PL9.7, R11.1
unnamed: C5.1, U1.1 (C1+)
unnamed: C5.2, U1.3 (C1-)
unnamed: C6.1, U1.4 (C2+)
unnamed: C6.2, U1.5 (C2-)
unnamed: C7.1, U1.2 (VS+)
unnamed: C9.1, U1.6 (VS-)
unnamed: U12.6 (1XTAL), XL3.1
unnamed: U12.7 (2XTAL), XL3.2
RXD: U1.10 (T2IN), U12.12 (RXD)
R/~W: U12.28 (R/~W); also elsewhere on the board
TXD: U1.12 (R1OUT), U12.10 (TXD)
~CTS: U1.9 (R2OUT), U12.9 (~CTS)
~DTR: U1.11 (T1IN), U12.11 (~DTR)
~IRQ: U12.26 (~IRQ); also elsewhere on the board
~P0: U12.3 (~CS1); also elsewhere on the board
~RES: U12.4 (~RESET); also elsewhere on the board

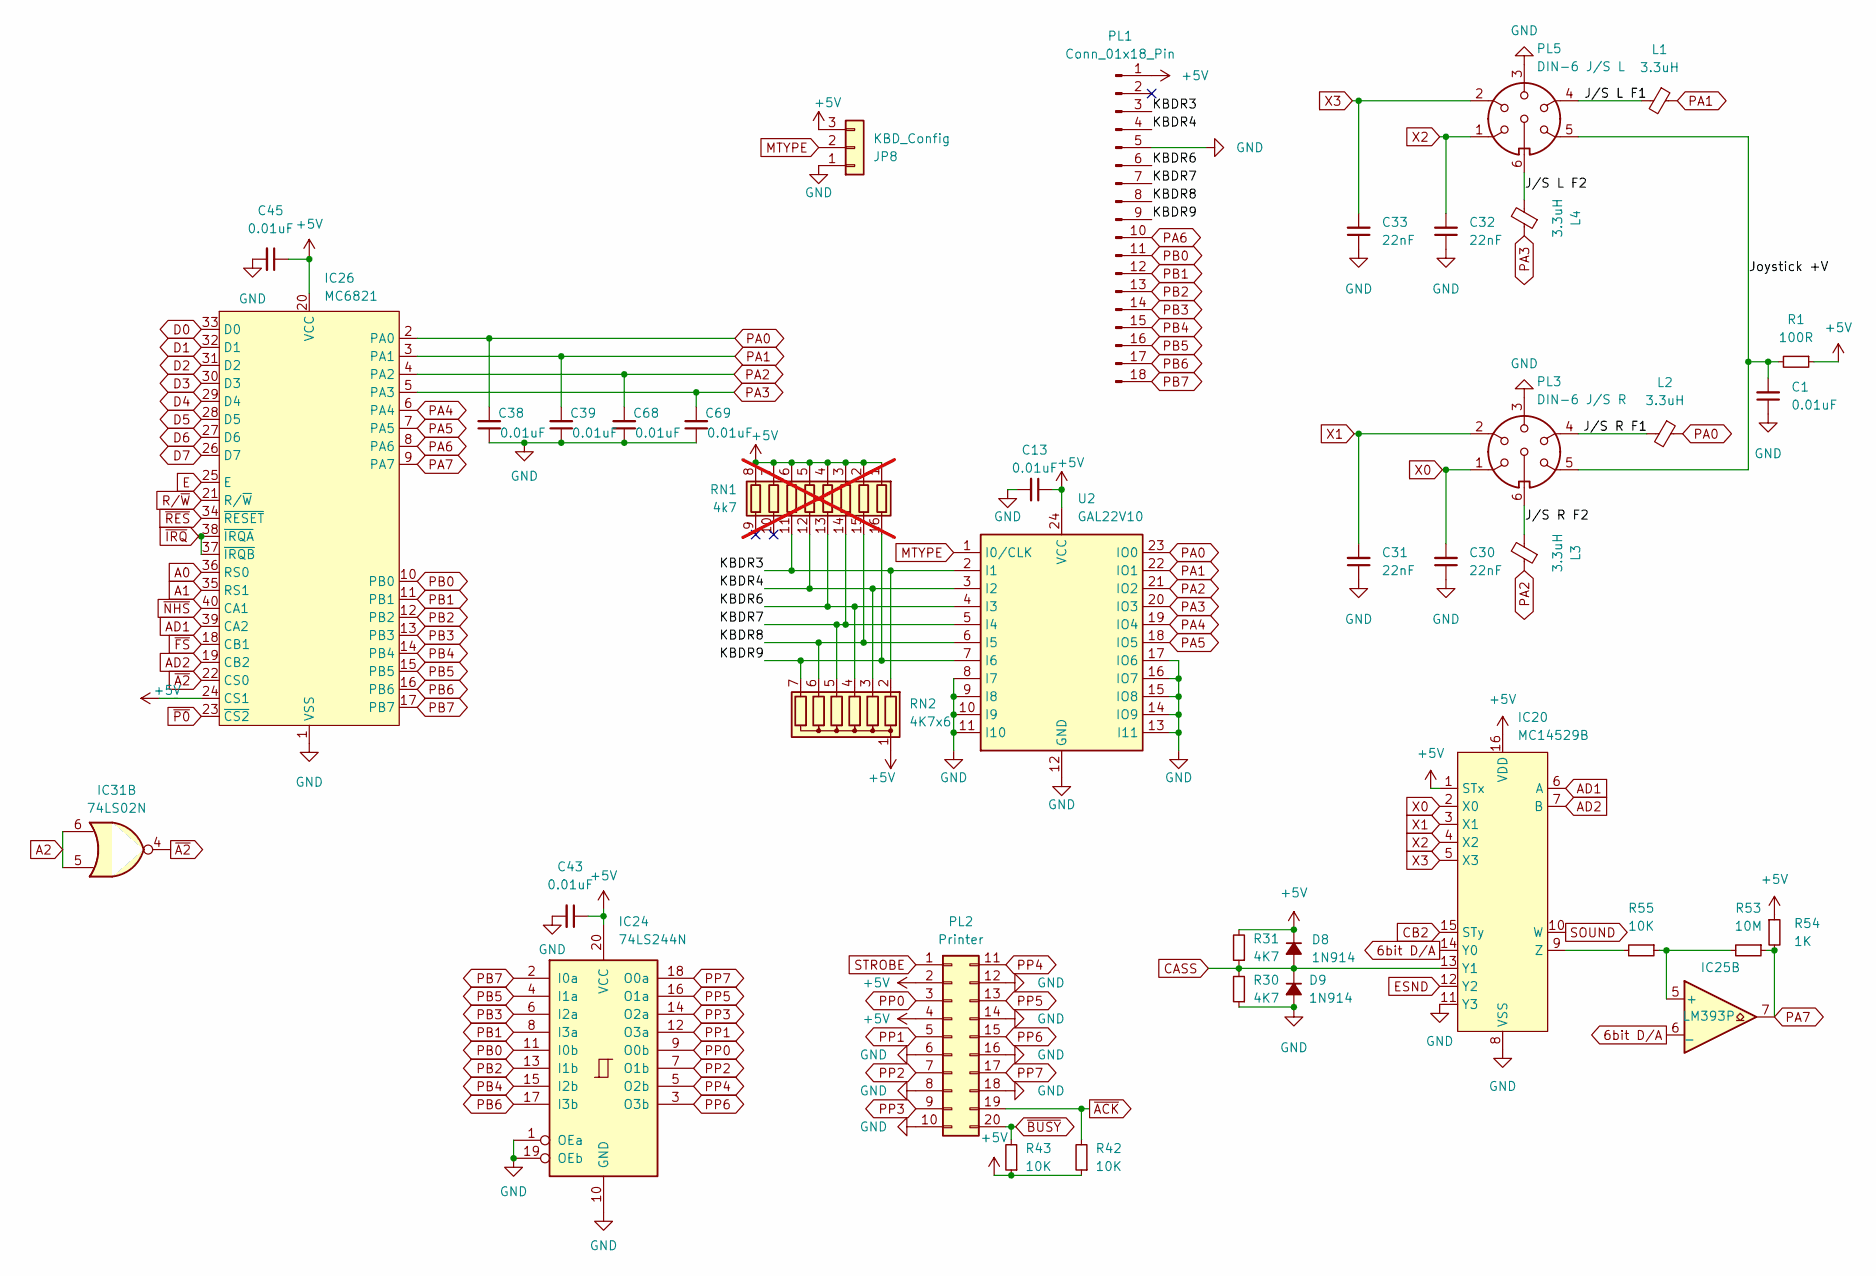
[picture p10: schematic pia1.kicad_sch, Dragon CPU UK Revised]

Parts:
C1, C13, C43, C45: 0.01uF; C_Disc_D4.3mm_W1.9mm_P5.00mm; DigiKey BC2662CT-ND
C30, C31, C32, C33: 22nF; C_0805_2012Metric_Pad1.18x1.45mm_HandSolder; LCSC C1729
C38, C39, C68, C69: 0.01uF; C_Disc_D4.3mm_W1.9mm_P5.00mm; DigiKey BC1101CT-ND
D8, D9: 1N914; D_DO-35_SOD27_P7.62mm_Horizontal; DigiKey 1N914FS-ND
IC20: MC14529B; DIP-16_W7.62mm; DigiKey CD4529BCN-ND
IC24: 74LS244N; DIP-20_W7.62mm; DigiKey 296-1653-5-ND
IC25: LM393P; DIP-8_W7.62mm; DigiKey 296-1398-5-ND
IC26: MC6821; DIP-40_W15.24mm; DigiKey 2156-MC6821CS-2156-ND
IC31: 74LS02N; DIP-14_W7.62mm; DigiKey 296-1627-5-ND
JP8: KBD_Config; PinHeader_1x03_P2.54mm_Vertical
L1, L2, L3, L4: 3.3uH; L_Axial_L7.0mm_D3.3mm_P5.08mm_Vertical_Fastron_MICC; DigiKey 495-5561-1-ND
PL1: Conn_01x18_Pin; PinHeader_1x18_P2.54mm_Vertical
PL2: Printer; IDC-Header_2x10-1MP_P2.54mm_Latch_Horizontal; DigiKey CHR20G-ND
PL3: DIN-6 J/S R; DIN-6_DELTRON_671-0601_Horizontal
PL5: DIN-6 J/S L; DIN-6_DELTRON_671-0601_Horizontal
R1: 100R; R_Axial_DIN0207_L6.3mm_D2.5mm_P10.16mm_Horizontal; DigiKey CF14JT100RCT-ND
R30, R31: 4K7; R_Axial_DIN0207_L6.3mm_D2.5mm_P2.54mm_Vertical; DigiKey CF14JT4K70CT-ND
R42, R43, R55: 10K; R_Axial_DIN0207_L6.3mm_D2.5mm_P10.16mm_Horizontal; DigiKey CF14JT10K0CT-ND
R53: 10M; R_Axial_DIN0207_L6.3mm_D2.5mm_P10.16mm_Horizontal; DigiKey CF14JT10M0CT-ND
R54: 1K; R_Axial_DIN0207_L6.3mm_D2.5mm_P10.16mm_Horizontal; DigiKey CF14JT1K00CT-ND
RN1: 4k7; R_Array_Convex_8x0602; DigiKey Y1472CT-ND; not fitted
RN2: 4K7x6; R_Array_SIP7; LCSC C39096
U2: GAL22V10; DIP-24_W7.62mm

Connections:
6bit D/A: IC20.14 (Y0), IC25.6 (_); also elsewhere on the board
+5V: C13.1, C43.1, C45.1, D8.1 (K), IC20.1 (STx), IC20.16 (VDD), IC24.20 (VCC), IC26.20 (VCC), IC26.24 (CS1), JP8.3, PL1.1, PL2.2, PL2.4, R1.1, R31.2, R42.1, R43.1, R54.1, RN1.1 (R1.1), RN1.2 (R2.1), RN1.3 (R3.1), RN1.4 (R4.1), RN1.5 (R5.1), RN1.6 (R6.1), RN1.7 (R7.1), RN1.8 (R8.1), RN2.1 (common), U2.24 (VCC); also elsewhere on the board
/PIA1/Joystick +V: C1.2, PL3.5, PL5.5, R1.2
/PIA1/J/S L F1: L1.2, PL5.4
/PIA1/J/S L F2: L4.2, PL5.6
/PIA1/J/S R F1: L2.2, PL3.4
/PIA1/J/S R F2: L3.2, PL3.6
/PIA1/KBDR3: PL1.3, RN1.11 (R6.2), RN2.2 (R1), U2.2 (I1)
/PIA1/KBDR4: PL1.4, RN1.12 (R5.2), RN2.3 (R2), U2.3 (I2)
/PIA1/KBDR6: PL1.6, RN1.13 (R4.2), RN2.4 (R3), U2.4 (I3)
/PIA1/KBDR7: PL1.7, RN1.14 (R3.2), RN2.5 (R4), U2.5 (I4)
/PIA1/KBDR8: PL1.8, RN1.15 (R2.2), RN2.6 (R5), U2.6 (I5)
/PIA1/KBDR9: PL1.9, RN1.16 (R1.2), RN2.7 (R6), U2.7 (I6)
A0: IC26.36 (RS0); also elsewhere on the board
A1: IC26.35 (RS1); also elsewhere on the board
A2: IC31.5, IC31.6; also elsewhere on the board
AD1: IC20.6 (A), IC26.39 (CA2)
AD2: IC20.7 (B), IC26.19 (CB2)
CASS: D8.2 (A), D9.1 (K), IC20.13 (Y1), R30.2, R31.1; also elsewhere on the board
CB2: IC20.15 (STy); also elsewhere on the board
D0: IC26.33 (D0); also elsewhere on the board
D1: IC26.32 (D1); also elsewhere on the board
D2: IC26.31 (D2); also elsewhere on the board
D3: IC26.30 (D3); also elsewhere on the board
D4: IC26.29 (D4); also elsewhere on the board
D5: IC26.28 (D5); also elsewhere on the board
D6: IC26.27 (D6); also elsewhere on the board
D7: IC26.26 (D7); also elsewhere on the board
E: IC26.25 (E); also elsewhere on the board
ESND: IC20.12 (Y2); also elsewhere on the board
MTYPE: JP8.2, U2.1 (I0/CLK); also elsewhere on the board
unnamed: IC20.9 (Z), R55.2
unnamed: IC25.5 (+), R53.2, R55.1
PA0: C38.2, IC26.2 (PA0), L2.1, U2.23 (IO0)
PA1: C39.2, IC26.3 (PA1), L1.1, U2.22 (IO1)
PA2: C68.2, IC26.4 (PA2), L3.1, U2.21 (IO2)
PA3: C69.2, IC26.5 (PA3), L4.1, U2.20 (IO3)
PA4: IC26.6 (PA4), U2.19 (IO4)
PA5: IC26.7 (PA5), U2.18 (IO5)
PA6: IC26.8 (PA6), PL1.10
PA7: IC25.7, IC26.9 (PA7), R53.1, R54.2
PB0: IC24.11 (I0b), IC26.10 (PB0), PL1.11
PB1: IC24.8 (I3a), IC26.11 (PB1), PL1.12
PB2: IC24.13 (I1b), IC26.12 (PB2), PL1.13
PB3: IC24.6 (I2a), IC26.13 (PB3), PL1.14
PB4: IC24.15 (I2b), IC26.14 (PB4), PL1.15
PB5: IC24.4 (I1a), IC26.15 (PB5), PL1.16
PB6: IC24.17 (I3b), IC26.16 (PB6), PL1.17
PB7: IC24.2 (I0a), IC26.17 (PB7), PL1.18
PP0: IC24.9 (O0b), PL2.3
PP1: IC24.12 (O3a), PL2.5
PP2: IC24.7 (O1b), PL2.7
PP3: IC24.14 (O2a), PL2.9
PP4: IC24.5 (O2b), PL2.11
PP5: IC24.16 (O1a), PL2.13
PP6: IC24.3 (O3b), PL2.15
PP7: IC24.18 (O0a), PL2.17
R/~W: IC26.21 (R/~W); also elsewhere on the board
SOUND: IC20.10 (W); also elsewhere on the board
STROBE: PL2.1; also elsewhere on the board
X0: C30.2, IC20.2 (X0), PL3.1
X1: C31.2, IC20.3 (X1), PL3.2
X2: C32.2, IC20.4 (X2), PL5.1
X3: C33.2, IC20.5 (X3), PL5.2
~A2: IC26.22 (CS0), IC31.4
~ACK: PL2.19, R42.2; also elsewhere on the board
~BUSY: PL2.20, R43.2; also elsewhere on the board
~FS: IC26.18 (CB1); also elsewhere on the board
~IRQ: IC26.37 (~IRQB), IC26.38 (~IRQA); also elsewhere on the board
~NHS: IC26.40 (CA1); also elsewhere on the board
~P0: IC26.23 (~CS2); also elsewhere on the board
~RES: IC26.34 (~RESET); also elsewhere on the board

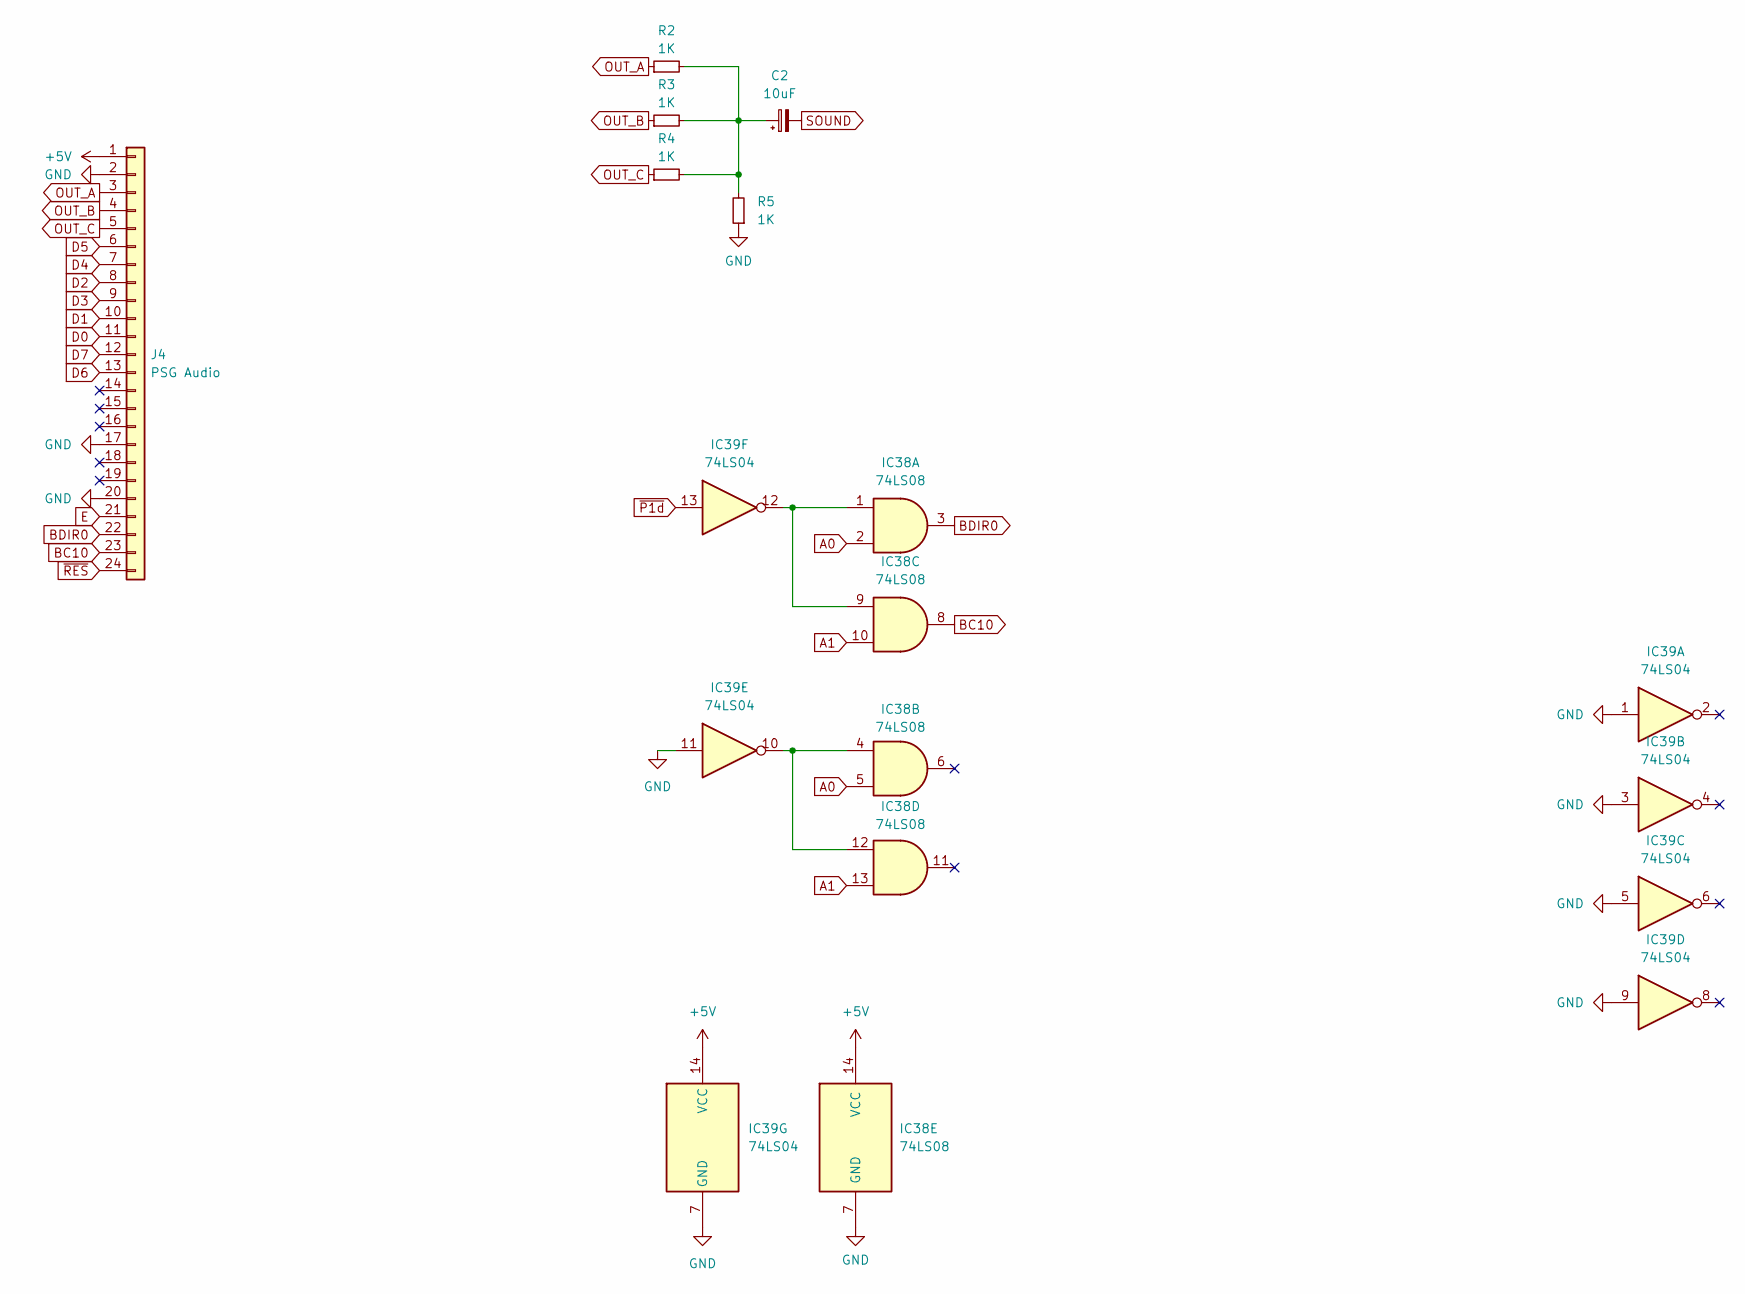
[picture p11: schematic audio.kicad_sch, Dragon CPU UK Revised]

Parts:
C2: 10uF; CP_Radial_D5.0mm_P2.50mm
IC38: 74LS08; DIP-14_W7.62mm; LCSC C22394768
IC39: 74LS04; DIP-14_W7.62mm; LCSC C22374093
J4: PSG Audio; AY-QTHT
R2, R3, R4: 1K; R_Axial_DIN0207_L6.3mm_D2.5mm_P10.16mm_Horizontal
R5: 1K; R_Axial_DIN0207_L6.3mm_D2.5mm_P2.54mm_Vertical

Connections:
+5V: IC38.14 (VCC), IC39.14 (VCC), J4.1; also elsewhere on the board
A0: IC38.2, IC38.5; also elsewhere on the board
A1: IC38.10, IC38.13; also elsewhere on the board
BC10: IC38.8, J4.23
BDIR0: IC38.3, J4.22
D0: J4.11; also elsewhere on the board
D1: J4.10; also elsewhere on the board
D2: J4.8; also elsewhere on the board
D3: J4.9; also elsewhere on the board
D4: J4.7; also elsewhere on the board
D5: J4.6; also elsewhere on the board
D6: J4.13; also elsewhere on the board
D7: J4.12; also elsewhere on the board
E: J4.21; also elsewhere on the board
unnamed: C2.1, R2.2, R3.2, R4.2, R5.2
unnamed: IC38.1, IC38.9, IC39.12
unnamed: IC38.4, IC38.12, IC39.10
OUT_A: J4.3, R2.1
OUT_B: J4.4, R3.1
OUT_C: J4.5, R4.1
SOUND: C2.2; also elsewhere on the board
~P1d: IC39.13; also elsewhere on the board
~RES: J4.24; also elsewhere on the board

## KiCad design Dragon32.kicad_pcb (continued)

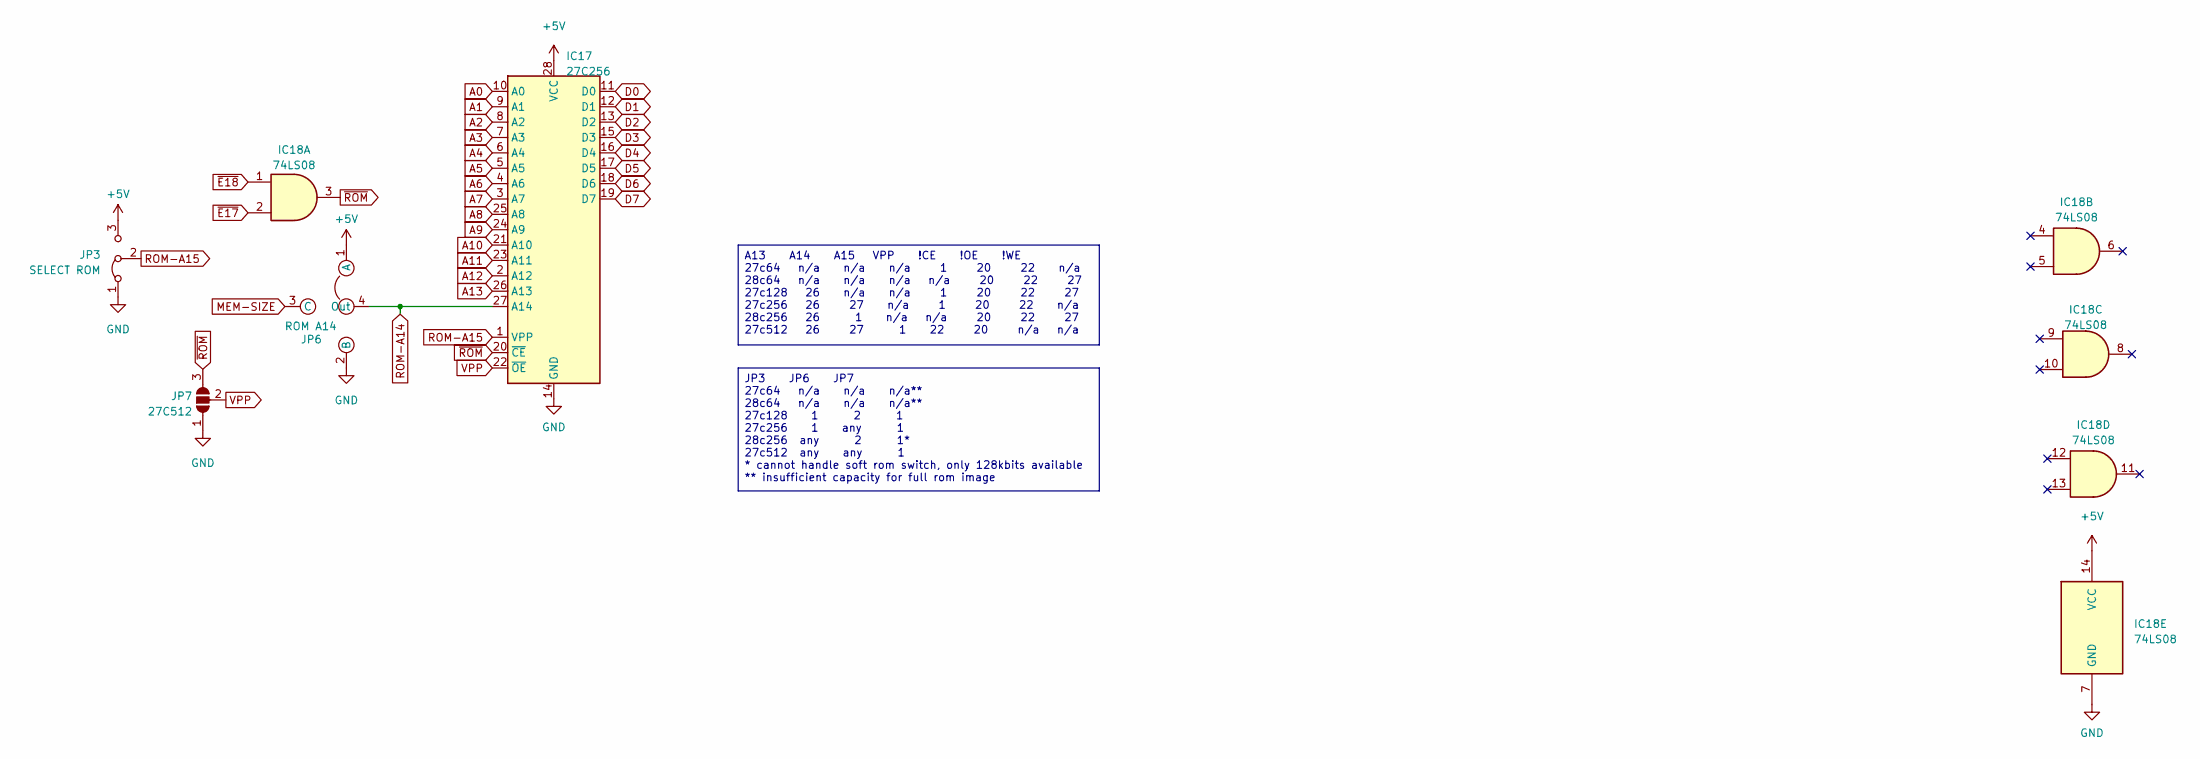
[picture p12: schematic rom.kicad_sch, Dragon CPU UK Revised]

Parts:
IC17: 27C256; DIP-28_W15.24mm
IC18: 74LS08; DIP-14_W7.62mm; LCSC C22394768
JP3: SELECT ROM; PinHeader_1x03_P2.54mm_Vertical
JP6: ROM A14; Jumper_4
JP7: 27C512; SolderJumper-3_P1.3mm_Open_Pad1.0x1.5mm

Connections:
+5V: IC17.28 (VCC), IC18.14 (VCC), JP3.3 (B), JP6.1 (A); also elsewhere on the board
A0: IC17.10 (A0); also elsewhere on the board
A1: IC17.9 (A1); also elsewhere on the board
A2: IC17.8 (A2); also elsewhere on the board
A3: IC17.7 (A3); also elsewhere on the board
A4: IC17.6 (A4); also elsewhere on the board
A5: IC17.5 (A5); also elsewhere on the board
A6: IC17.4 (A6); also elsewhere on the board
A7: IC17.3 (A7); also elsewhere on the board
A8: IC17.25 (A8); also elsewhere on the board
A9: IC17.24 (A9); also elsewhere on the board
A10: IC17.21 (A10); also elsewhere on the board
A11: IC17.23 (A11); also elsewhere on the board
A12: IC17.2 (A12); also elsewhere on the board
A13: IC17.26 (A13); also elsewhere on the board
D0: IC17.11 (D0); also elsewhere on the board
D1: IC17.12 (D1); also elsewhere on the board
D2: IC17.13 (D2); also elsewhere on the board
D3: IC17.15 (D3); also elsewhere on the board
D4: IC17.16 (D4); also elsewhere on the board
D5: IC17.17 (D5); also elsewhere on the board
D6: IC17.18 (D6); also elsewhere on the board
D7: IC17.19 (D7); also elsewhere on the board
MEM-SIZE: JP6.3 (C); also elsewhere on the board
ROM-A14: IC17.27 (A14), JP6.4 (Out); also elsewhere on the board
ROM-A15: IC17.1 (VPP), JP3.2 (C); also elsewhere on the board
VPP: IC17.22 (~OE), JP7.2 (C)
~E17: IC18.2; also elsewhere on the board
~E18: IC18.1; also elsewhere on the board
~ROM: IC17.20 (~CE), IC18.3, JP7.3 (B)

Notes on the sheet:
JP3 JP6 JP7 27c64 n/a n/a n/a** 28c64 n/a n/a n/a** 27c128 1 2 1 27c256 1 any 1 28c256 any 2 1* 27c512 any any 1 * cannot handle soft rom switch, only 128kbits available ** insufficient capacity for full rom image
A13 A14 A15 VPP !CE !OE !WE 27c64 n/a n/a n/a 1 20 22 n/a 28c64 n/a n/a n/a n/a 20 22 27 27c128 26 n/a n/a 1 20 22 27 27c256 26 27 n/a 1 20 22 n/a 28c256 26 1 n/a n/a 20 22 27 27c512 26 27 1 22 20 n/a n/a

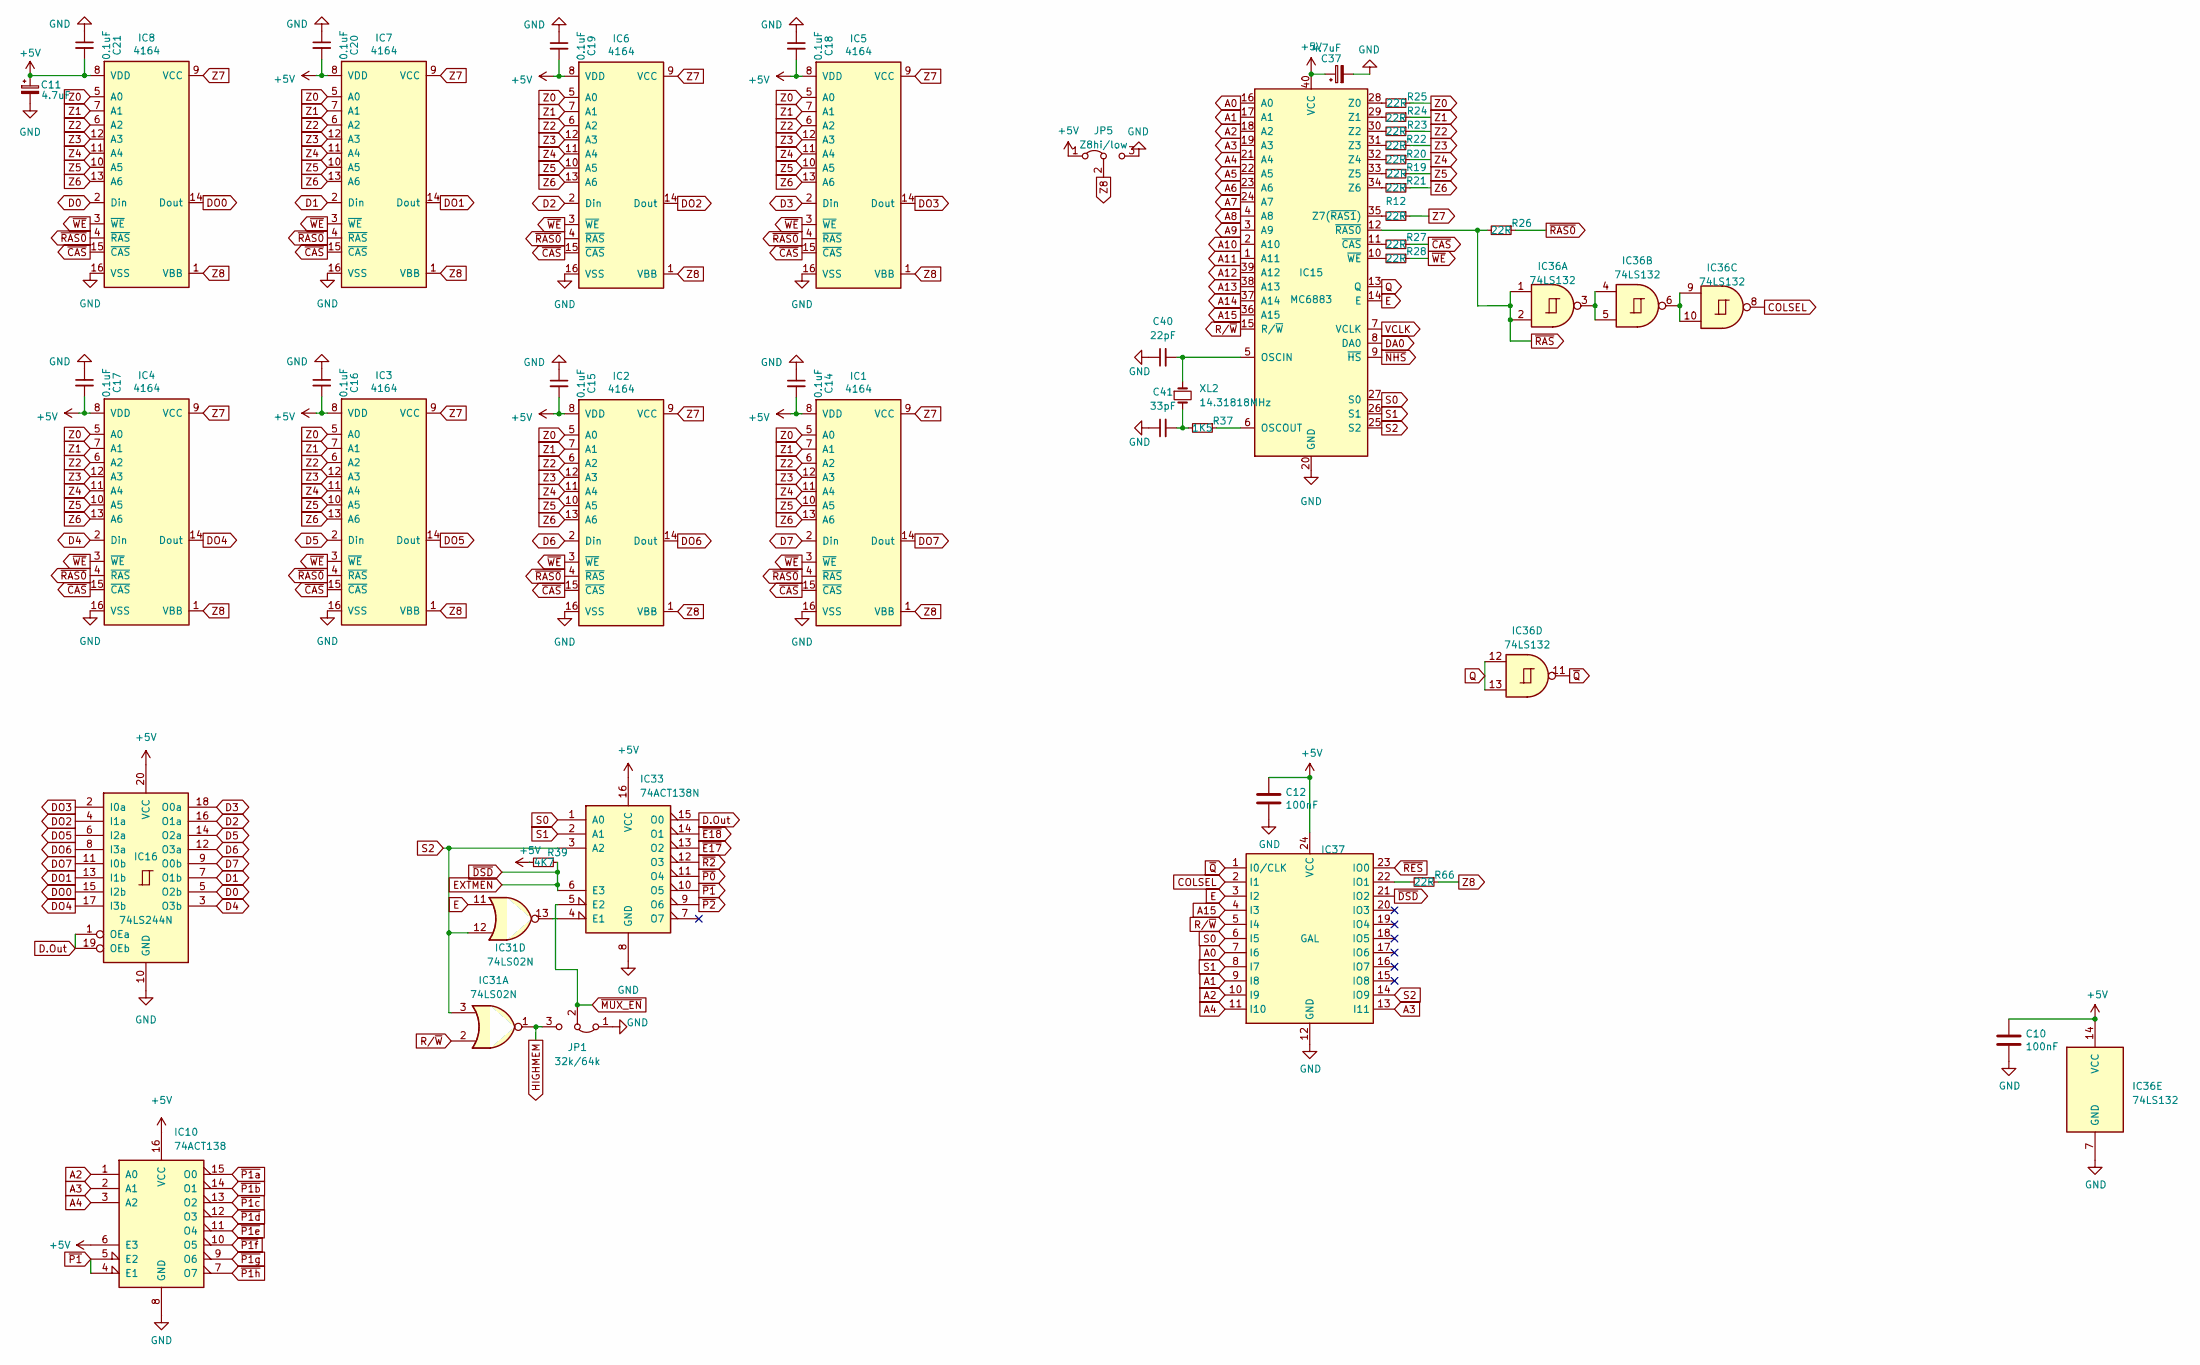
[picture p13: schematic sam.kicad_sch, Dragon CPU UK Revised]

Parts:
C10, C12: 100nF; C_0805_2012Metric_Pad1.18x1.45mm_HandSolder; LCSC C1711
C11, C37: 4.7uF; CP_Radial_D5.0mm_P2.50mm; DigiKey 478-8984-1-ND
C14, C15, C16, C17, C18, C19, C20, C21: 0.1uF; C_Disc_D4.3mm_W1.9mm_P5.00mm; DigiKey BC1101CT-ND
C40: 22pF; C_0603_1608Metric_Pad1.08x0.95mm_HandSolder; LCSC C1653
C41: 33pF; C_0603_1608Metric_Pad1.08x0.95mm_HandSolder; LCSC C1663
IC1, IC2, IC3, IC4, IC5, IC6, IC7, IC8: 4164; DIP-16_W7.62mm
IC10: 74ACT138; DIP-16_W7.62mm; LCSC C1547282
IC15: MC6883; DIP-40_W15.24mm
IC16: 74LS244N; DIP-20_W7.62mm; DigiKey 296-1653-5-ND
IC31: 74LS02N; DIP-14_W7.62mm; DigiKey 296-1627-5-ND
IC33: 74ACT138N; DIP-16_W7.62mm; DigiKey 296-1639-5-ND
IC36: 74LS132; DIP-14_W7.62mm
IC37: GAL; DIP-24_W7.62mm
JP1: 32k/64k; PinHeader_1x03_P2.54mm_Vertical
JP5: Z8hi/low; SolderJumper-3_P1.3mm_Open_Pad1.0x1.5mm
R12, R19, R20, R21, R22, R23, R24, R25, R26, R27, R28, R66: 22R; R_0805_2012Metric_Pad1.20x1.40mm_HandSolder; LCSC C17561
R37: 1K5; R_0603_1608Metric_Pad1.05x0.95mm_HandSolder; LCSC C22843
R39: 4K7; R_Axial_DIN0207_L6.3mm_D2.5mm_P2.54mm_Vertical; DigiKey CF14JT4K70CT-ND
XL2: 14.31818MHz; Crystal_HC49-U_Horizontal; DigiKey CTX088-ND

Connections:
+5V: C10.1, C11.1, C12.1, C14.2, C15.2, C16.2, C17.2, C18.2, C19.2, C20.2, C21.2, C37.1, IC1.8 (VDD), IC2.8 (VDD), IC3.8 (VDD), IC4.8 (VDD), IC5.8 (VDD), IC6.8 (VDD), IC7.8 (VDD), IC8.8 (VDD), IC10.6 (E3), IC10.16 (VCC), IC15.40 (VCC), IC16.20 (VCC), IC33.16 (VCC), IC36.14 (VCC), IC37.24 (VCC), JP5.1 (A), R39.2; also elsewhere on the board
A0: IC15.16 (A0), IC37.7 (I6); also elsewhere on the board
A1: IC15.17 (A1), IC37.9 (I8); also elsewhere on the board
A2: IC10.1 (A0), IC15.18 (A2), IC37.10 (I9); also elsewhere on the board
A3: IC10.2 (A1), IC15.19 (A3), IC37.13 (I11); also elsewhere on the board
A4: IC10.3 (A2), IC15.21 (A4), IC37.11 (I10); also elsewhere on the board
A5: IC15.22 (A5); also elsewhere on the board
A6: IC15.23 (A6); also elsewhere on the board
A7: IC15.24 (A7); also elsewhere on the board
A8: IC15.4 (A8); also elsewhere on the board
A9: IC15.3 (A9); also elsewhere on the board
A10: IC15.2 (A10); also elsewhere on the board
A11: IC15.1 (A11); also elsewhere on the board
A12: IC15.39 (A12); also elsewhere on the board
A13: IC15.38 (A13); also elsewhere on the board
A14: IC15.37 (A14); also elsewhere on the board
A15: IC15.36 (A15), IC37.4 (I3); also elsewhere on the board
COLSEL: IC36.8, IC37.2 (I1)
D0: IC8.2 (Din), IC16.5 (O2b); also elsewhere on the board
D1: IC7.2 (Din), IC16.7 (O1b); also elsewhere on the board
D2: IC6.2 (Din), IC16.16 (O1a); also elsewhere on the board
D3: IC5.2 (Din), IC16.18 (O0a); also elsewhere on the board
D4: IC4.2 (Din), IC16.3 (O3b); also elsewhere on the board
D5: IC3.2 (Din), IC16.14 (O2a); also elsewhere on the board
D6: IC2.2 (Din), IC16.12 (O3a); also elsewhere on the board
D7: IC1.2 (Din), IC16.9 (O0b); also elsewhere on the board
D.Out: IC16.1 (OEa), IC16.19 (OEb), IC33.15 (O0)
DA0: IC15.8 (DA0); also elsewhere on the board
DO0: IC8.14 (Dout), IC16.15 (I2b); also elsewhere on the board
DO1: IC7.14 (Dout), IC16.13 (I1b); also elsewhere on the board
DO2: IC6.14 (Dout), IC16.4 (I1a); also elsewhere on the board
DO3: IC5.14 (Dout), IC16.2 (I0a); also elsewhere on the board
DO4: IC4.14 (Dout), IC16.17 (I3b); also elsewhere on the board
DO5: IC3.14 (Dout), IC16.6 (I2a); also elsewhere on the board
DO6: IC2.14 (Dout), IC16.8 (I3a); also elsewhere on the board
DO7: IC1.14 (Dout), IC16.11 (I0b); also elsewhere on the board
E: IC15.14 (E), IC31.11, IC37.3 (I2); also elsewhere on the board
EXTMEN: IC33.6 (E3), IC37.21 (IO2), R39.1; also elsewhere on the board
HIGHMEM: IC31.1, JP1.3 (B); also elsewhere on the board
unnamed: C41.2, R37.2, XL2.2
unnamed: C40.2, IC15.5 (OSCIN), XL2.1
unnamed: IC15.6 (OSCOUT), R37.1
unnamed: IC15.28 (Z0), R25.2
unnamed: IC15.29 (Z1), R24.2
unnamed: IC15.30 (Z2), R23.2
unnamed: IC15.31 (Z3), R22.2
unnamed: IC15.32 (Z4), R20.2
unnamed: IC15.33 (Z5), R19.2
unnamed: IC15.34 (Z6), R21.2
unnamed: IC15.35 (Z7(~RAS1)), R12.2
unnamed: IC15.11 (~CAS), R27.2
unnamed: IC15.10 (~WE), R28.2
unnamed: IC31.13, IC33.4 (E1)
unnamed: IC36.3, IC36.4, IC36.5
unnamed: IC36.6, IC36.9, IC36.10
unnamed: IC37.22 (IO1), R66.2
Q: IC15.13 (Q), IC36.12, IC36.13; also elsewhere on the board
R/~W: IC15.15 (R/~W), IC31.2, IC37.5 (I4); also elsewhere on the board
S0: IC15.27 (S0), IC33.1 (A0), IC37.6 (I5)
S1: IC15.26 (S1), IC33.2 (A1), IC37.8 (I7)
S2: IC15.25 (S2), IC31.3, IC31.12, IC33.3 (A2), IC37.14 (IO9)
VCLK: IC15.7 (VCLK); also elsewhere on the board
Z0: IC1.5 (A0), IC2.5 (A0), IC3.5 (A0), IC4.5 (A0), IC5.5 (A0), IC6.5 (A0), IC7.5 (A0), IC8.5 (A0), R25.1
Z1: IC1.7 (A1), IC2.7 (A1), IC3.7 (A1), IC4.7 (A1), IC5.7 (A1), IC6.7 (A1), IC7.7 (A1), IC8.7 (A1), R24.1
Z2: IC1.6 (A2), IC2.6 (A2), IC3.6 (A2), IC4.6 (A2), IC5.6 (A2), IC6.6 (A2), IC7.6 (A2), IC8.6 (A2), R23.1
Z3: IC1.12 (A3), IC2.12 (A3), IC3.12 (A3), IC4.12 (A3), IC5.12 (A3), IC6.12 (A3), IC7.12 (A3), IC8.12 (A3), R22.1
Z4: IC1.11 (A4), IC2.11 (A4), IC3.11 (A4), IC4.11 (A4), IC5.11 (A4), IC6.11 (A4), IC7.11 (A4), IC8.11 (A4), R20.1
Z5: IC1.10 (A5), IC2.10 (A5), IC3.10 (A5), IC4.10 (A5), IC5.10 (A5), IC6.10 (A5), IC7.10 (A5), IC8.10 (A5), R19.1
Z6: IC1.13 (A6), IC2.13 (A6), IC3.13 (A6), IC4.13 (A6), IC5.13 (A6), IC6.13 (A6), IC7.13 (A6), IC8.13 (A6), R21.1
Z7: IC1.9 (VCC), IC2.9 (VCC), IC3.9 (VCC), IC4.9 (VCC), IC5.9 (VCC), IC6.9 (VCC), IC7.9 (VCC), IC8.9 (VCC), R12.1
Z8: IC1.1 (VBB), IC2.1 (VBB), IC3.1 (VBB), IC4.1 (VBB), IC5.1 (VBB), IC6.1 (VBB), IC7.1 (VBB), IC8.1 (VBB), JP5.2 (C), R66.1
~CAS: IC1.15 (~CAS), IC2.15 (~CAS), IC3.15 (~CAS), IC4.15 (~CAS), IC5.15 (~CAS), IC6.15 (~CAS), IC7.15 (~CAS), IC8.15 (~CAS), R27.1
~E17: IC33.13 (O2); also elsewhere on the board
~E18: IC33.14 (O1); also elsewhere on the board
~MUX_EN: IC33.5 (E2), JP1.2 (C); also elsewhere on the board
~NHS: IC15.9 (~HS); also elsewhere on the board
~P0: IC33.11 (O4); also elsewhere on the board
~P1a: IC10.15 (O0); also elsewhere on the board
~P1b: IC10.14 (O1); also elsewhere on the board
~P1c: IC10.13 (O2); also elsewhere on the board
~P1d: IC10.12 (O3); also elsewhere on the board
~P1e: IC10.11 (O4)
~P1f: IC10.10 (O5)
~P1g: IC10.9 (O6)
~P1h: IC10.7 (O7)
~P1: IC10.4 (E1), IC10.5 (E2), IC33.10 (O5)
~P2: IC33.9 (O6); also elsewhere on the board
~Q: IC36.11, IC37.1 (I0/CLK)
~R2: IC33.12 (O3); also elsewhere on the board
~RAS0: IC1.4 (~RAS), IC2.4 (~RAS), IC3.4 (~RAS), IC4.4 (~RAS), IC5.4 (~RAS), IC6.4 (~RAS), IC7.4 (~RAS), IC8.4 (~RAS), R26.1
~RAS: IC15.12 (~RAS0), IC36.1, IC36.2, R26.2; also elsewhere on the board
~RES: IC37.23 (IO0); also elsewhere on the board
~WE: IC1.3 (~WE), IC2.3 (~WE), IC3.3 (~WE), IC4.3 (~WE), IC5.3 (~WE), IC6.3 (~WE), IC7.3 (~WE), IC8.3 (~WE), R28.1

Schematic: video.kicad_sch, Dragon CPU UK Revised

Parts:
J1: Video Output Female; PinSocket_1x05_P2.54mm_Vertical
J2: Board Interconnect Female; PinSocket_2x11_P2.54mm_Vertical
J3: Conn_02x08_Odd_Even; PinSocket_2x08_P2.54mm_Vertical
PL6: Conn_01x09_Male; Molex_KK-396_A-41791-0009_1x09_P3.96mm_Vertical; DigiKey 2057-LHD-09-TS-ND

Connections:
+5V: J1.2, J2.1, PL6.2, PL6.8; also elsewhere on the board
+12V: PL6.1; also elsewhere on the board
-5V: J1.3, PL6.3; also elsewhere on the board
A0: J3.2; also elsewhere on the board
A1: J3.4; also elsewhere on the board
A2: J3.6; also elsewhere on the board
A3: J3.8; also elsewhere on the board
BIAS: J1.1, PL6.9
CSS: J2.19; also elsewhere on the board
D0: J3.1; also elsewhere on the board
D1: J3.3; also elsewhere on the board
D2: J3.5; also elsewhere on the board
D3: J3.7; also elsewhere on the board
D4: J3.9; also elsewhere on the board
D5: J3.11; also elsewhere on the board
D6: J3.13; also elsewhere on the board
D7: J3.15; also elsewhere on the board
DA0: J2.6; also elsewhere on the board
DO0: J2.3; also elsewhere on the board
DO1: J2.5; also elsewhere on the board
DO2: J2.7; also elsewhere on the board
DO3: J2.9; also elsewhere on the board
DO4: J2.11; also elsewhere on the board
DO5: J2.13; also elsewhere on the board
DO6: J2.15; also elsewhere on the board
DO7: J2.17; also elsewhere on the board
E: J3.16; also elsewhere on the board
GM0: J2.14; also elsewhere on the board
GM1: J2.12; also elsewhere on the board
GM2: J2.10; also elsewhere on the board
R/~W: J3.14; also elsewhere on the board
SOUND: PL6.7; also elsewhere on the board
VCLK: J2.18; also elsewhere on the board
VID OUT: J1.4, PL6.6
~A/G: J2.20; also elsewhere on the board
~FS: J2.22; also elsewhere on the board
~NHS: J2.8; also elsewhere on the board
~P1b: J3.12; also elsewhere on the board
~P1c: J3.10; also elsewhere on the board
~RAS: J2.16; also elsewhere on the board
~RES: J2.2; also elsewhere on the board

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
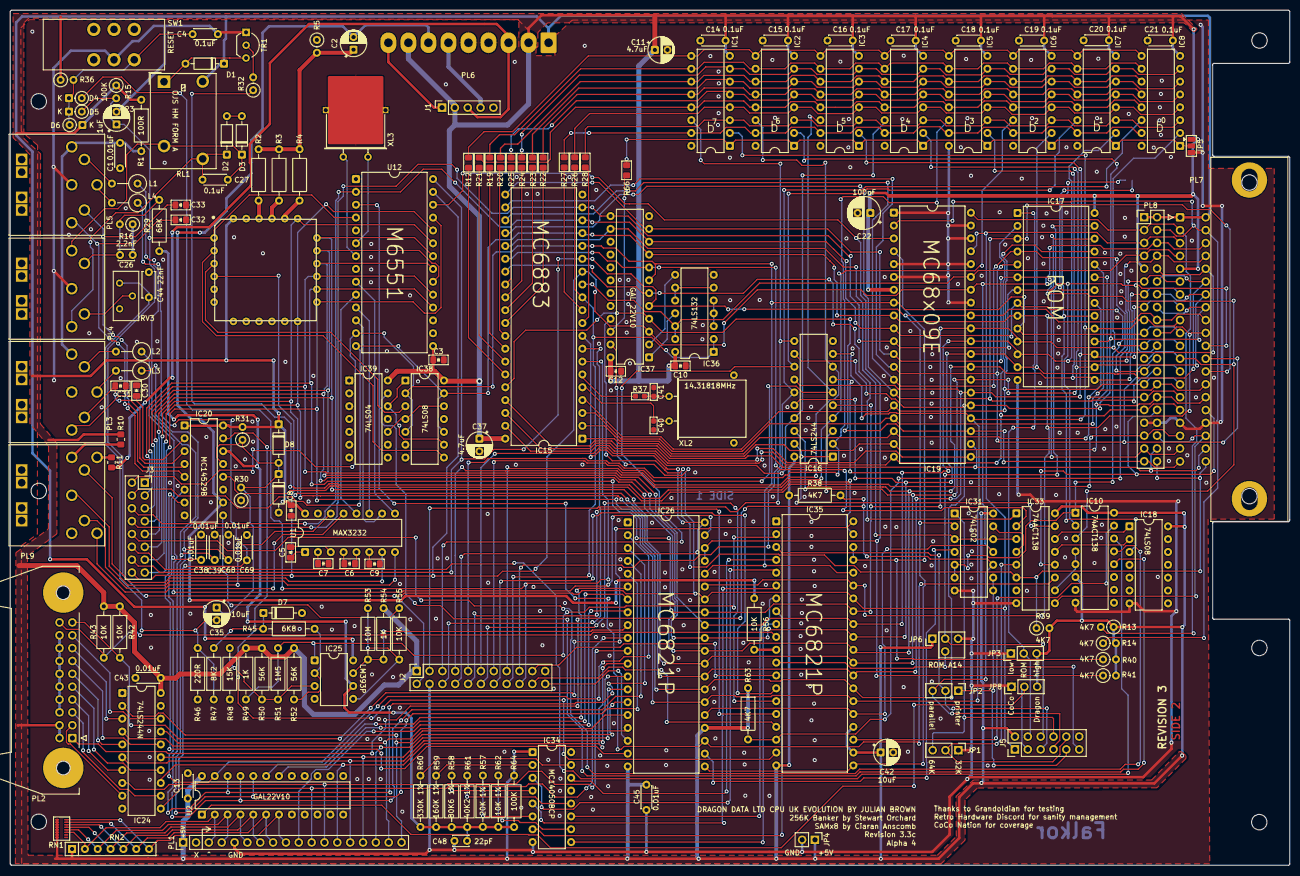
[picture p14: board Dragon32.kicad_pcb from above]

Board: 2 copper layers, 253.0 x 169.1 mm, 169 parts (1 on the bottom side), 218 nets.

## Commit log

2023-05-29 repack layout
    [Dragon32.kicad_sch, sam.kicad_sch]
2023-05-29 add 256 banking
    [sam.kicad_sch]
2023-05-30 handle 27C512
    [pia2.kicad_sch, rom.kicad_sch, sam.kicad_sch]
2023-06-01 remove video
    [Dragon32.kicad_sch, vdg.kicad_sch, video.kicad_sch]
2023-08-27 add control for pia 3
    [Dragon32.kicad_pcb, pia2.kicad_sch, sam.kicad_sch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]
2023-08-27 add power pin to keyboard connection
    [Dragon32.kicad_pcb, pia1.kicad_sch]
2023-10-02 complete tracing for fabrication
    [Dragon32.kicad_pcb, pia2.kicad_sch, video.kicad_sch]
2023-11-13 fix rom and pia select traces
    [mpu.kicad_sch, pia2.kicad_sch, rom.kicad_sch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]
2024-01-14 refresh board for alpha 3
2024-03-04 move -5v
    [video.kicad_sch]
2024-03-16 reinforce power rails
    [Dragon32.kicad_sch, pia2.kicad_sch, video.kicad_sch]
2025-01-26 reinforce audio traces
    [Dragon32.kicad_sch, audio.kicad_sch, mpu.kicad_sch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]
2025-01-26 update readme, tidy up
    [serial.kicad_sch]
2025-08-09 migrate to kicad 9
    [Dragon32.kicad_sch, audio.kicad_sch, mpu.kicad_sch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]
2025-08-10 redo layout for SAMx8
    [sam.kicad_sch, video.kicad_sch]
2025-08-10 add uart to board
    [Dragon32.kicad_sch, pia1.kicad_sch, sam.kicad_sch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]
2025-10-05 update to keyboard switch option
    [Dragon32.csv, Dragon32.kicad_pcb, Dragon32.kicad_sch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]
